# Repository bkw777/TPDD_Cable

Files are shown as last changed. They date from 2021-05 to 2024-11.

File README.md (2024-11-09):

# Cable for [Tandy Portable Disk Drive](http://tandy.wiki/TPDD)

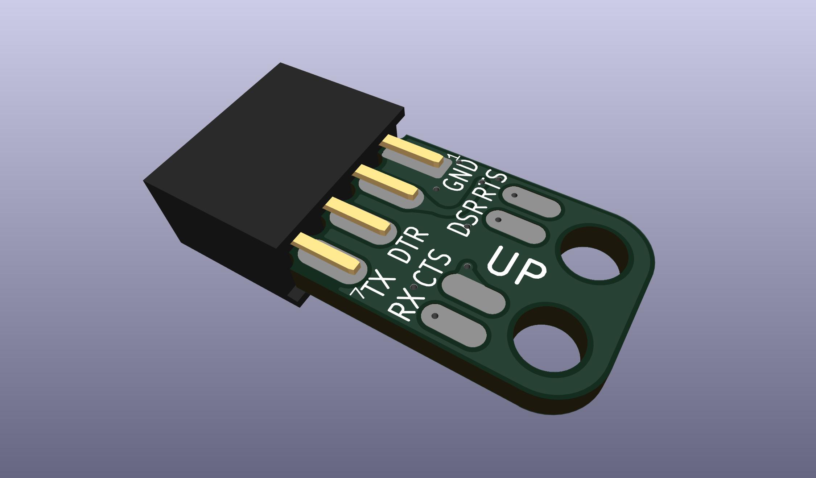
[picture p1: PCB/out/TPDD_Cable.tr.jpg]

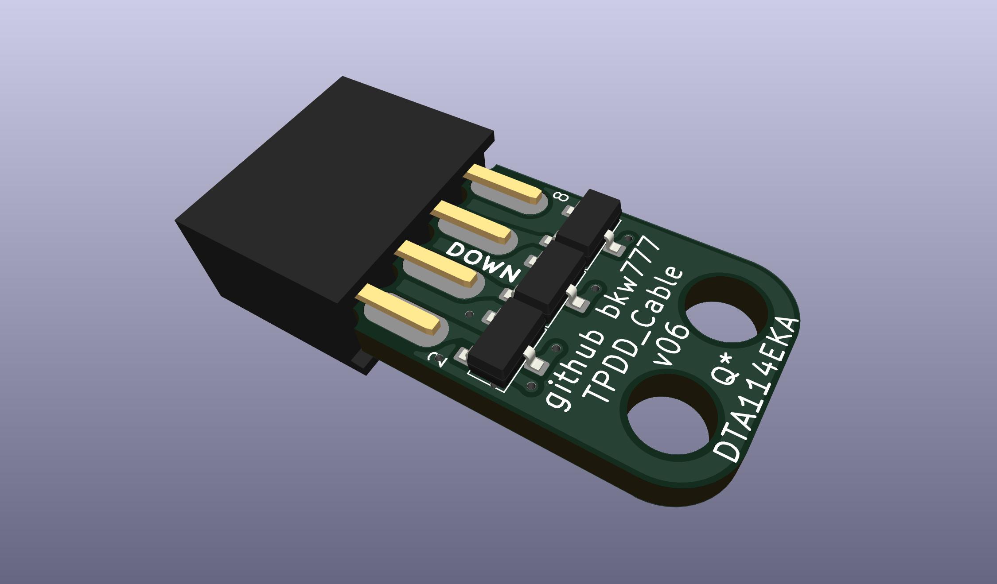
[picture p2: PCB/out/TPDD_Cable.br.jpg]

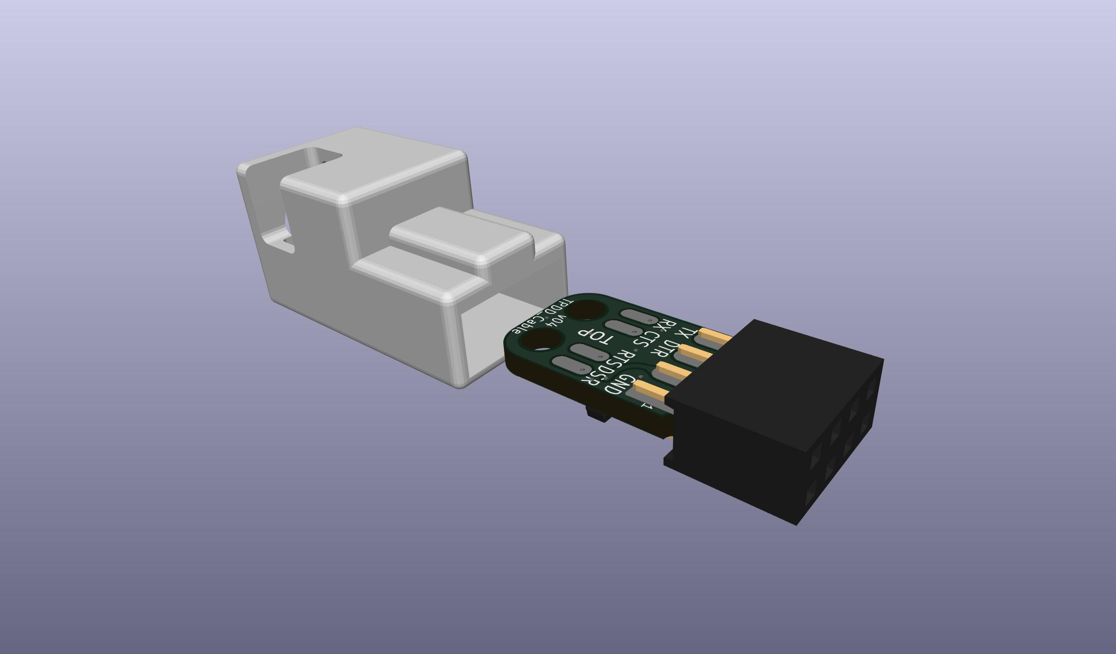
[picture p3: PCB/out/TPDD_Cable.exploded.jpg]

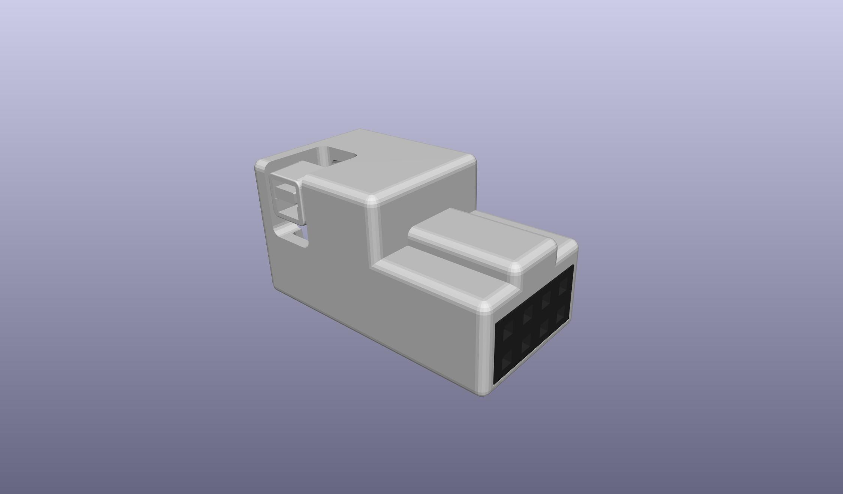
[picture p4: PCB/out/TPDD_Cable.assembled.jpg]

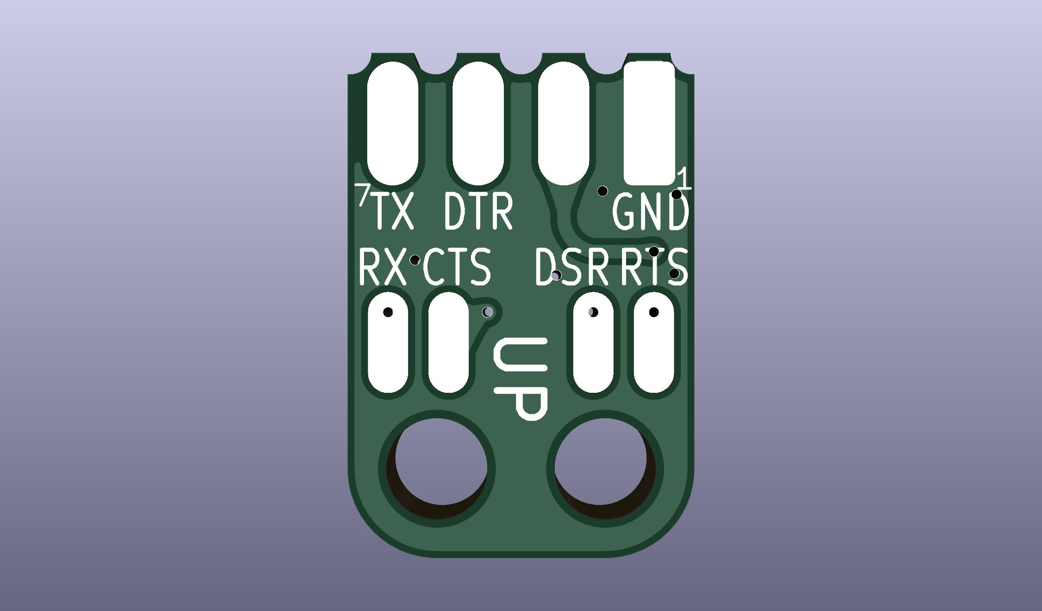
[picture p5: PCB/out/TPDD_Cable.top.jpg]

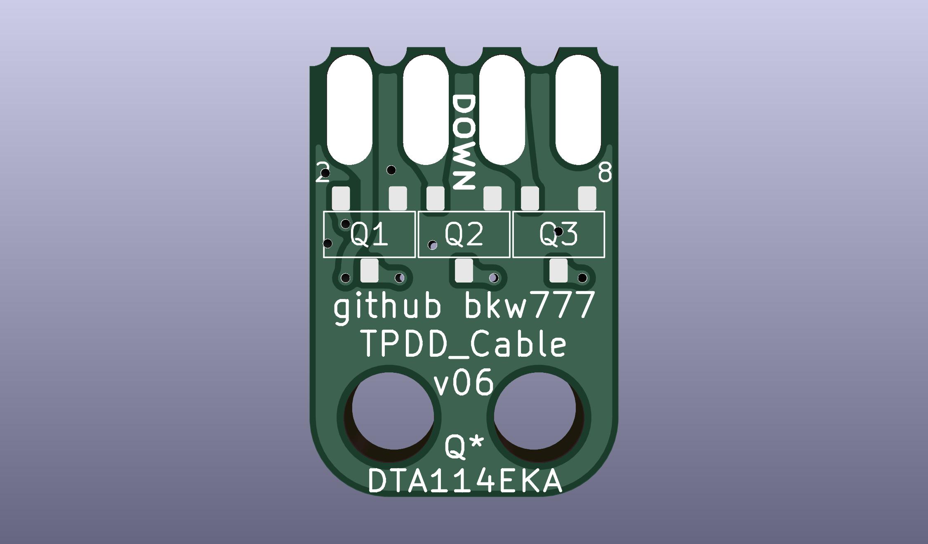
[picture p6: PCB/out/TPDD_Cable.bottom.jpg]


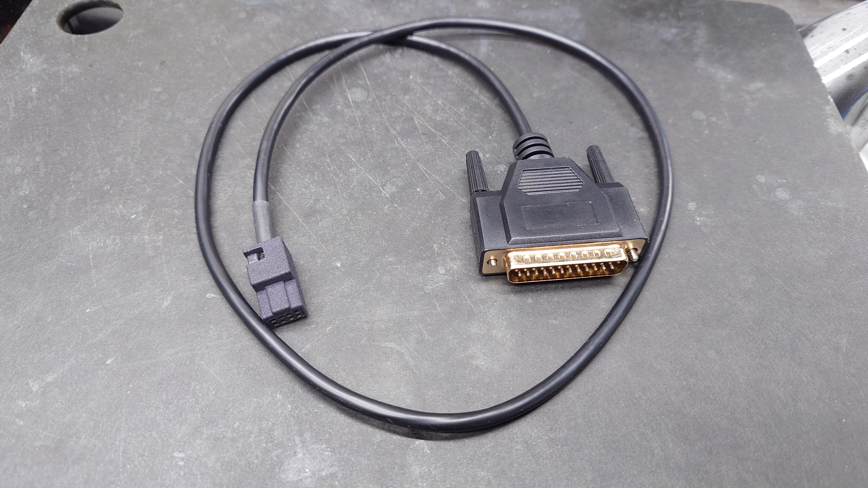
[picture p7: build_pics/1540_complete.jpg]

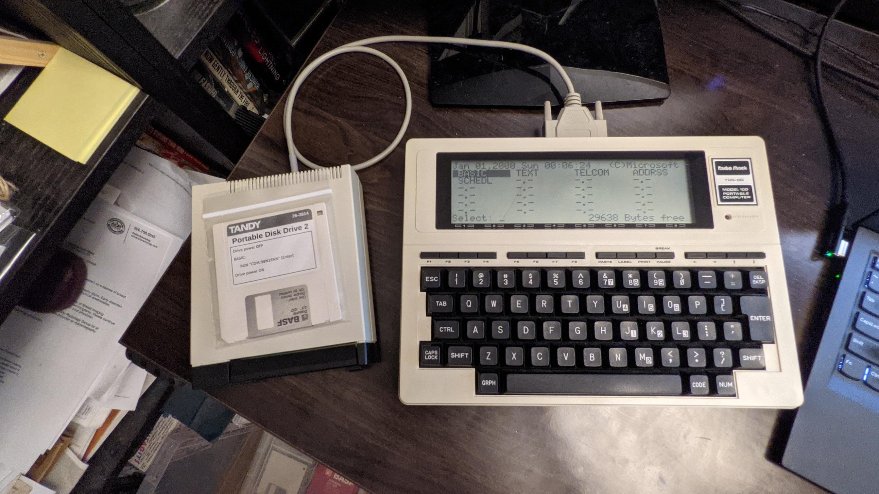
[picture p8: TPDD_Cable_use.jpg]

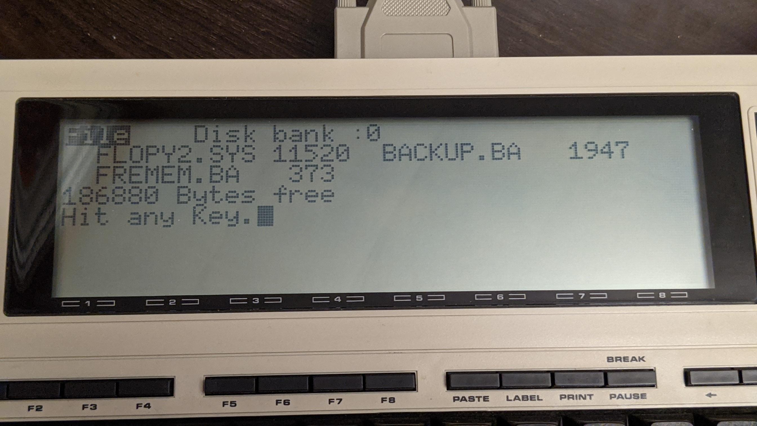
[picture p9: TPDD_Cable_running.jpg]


# Parts
PCB & Housing (and solder jig): [PCBWAY](https://www.pcbway.com/project/shareproject/TANDY_Portable_Disk_Drive_Cable.html)  
BOM: [DigiKey](https://www.digikey.com/short/87q1nv0f)  

The BOM includes a grey cable. This [black cable](https://www.digikey.com/short/wbpp81nt) can be substituted if you want.

# Directions

[pictures of build process](build_pics/build_pics.md)
<!--
Assembly pictures: <https://photos.app.goo.gl/TdYxGhzK94KT9rS78>
(old method before the 3d-printed housing)
-->

If you want to make 2 cables, one for Model 100 and one for PC/WP-2, then double the BOM components except for the cable, and cut the cable in half right in the middle.  
Otherwise just cut off the 9-pin plug to make one longer cable for Model 100 and other KC-85 clones.

## prepare the cable

Cut the unwanted plug off the cable.  
If building a Model 100 cable, cut off the 9-pin plug.  
If building a PC/WP-2 cable, cut off the 25-pin plug.  
If building both cables, cut the cable in half in the middle.

Strip off about 1 inch or 25mm of the cable jacket.  
Also cut the foil shield and the bare wire short right at the end of the jacket.

Apply a bit of flux to the ends of the loose wires.

Load up the soldering iron with a ball of solder and touch the soldering iron to the end of each wire long enough for the insulation to shrink itself back about 1-2mm and tin the end of the wire at the same time. You only need about 1mm of wire exposed and it's not worth trying to actually strip the insulation the normal way. Just heat the very tip end and it will melt and shrink itself back the perfect amount and the wire will end up tinned as well.

Insert the cable into the round opening on the housing and push the cable all the way through the housing and slide the housing about a foot back from the end of the cable.

Thread a 1 to 1-1/2 inch (25-30mm) piece of heatshrink onto the cable and slide back to the housing.  
Don't shrink it.

## Map the wire colors to the plug pin numbers

Print the wire color worksheet.

Put a DMM into continuity mode.

Use a jumper wire or meter lead with an alligator clip to grab one of the wires and connect to one lead of the DMM.

Probe with the other meter lead to touch each pin on the DB25 to find which pin that wire goes to.

Write the color of the wire for that pin number on the worksheet.

Repeat for all wires.

Cut the un-used wires short.
For the exact cable in the BOM and probably most cables, there will be 3 wires with no place on the PCB: a bare wire connected to both the DB25 shell and pin 1, a wire on pin 8, and a wire on pin 22.  
Cut all of those as short as possible right at the end of the cable jacket.

## prepare the pcb
Sand the edge of the pcb as neccessary to flatten any pointy bits left from the edge routing. The front edge is supposed to be castellated, so don't try to grind those away, but the front edge is supposed to be straight, so sand flat anything that sticks out from the rest.

Blunt or chamfer the rim of the drill holes on the bottom side of the pcb (the side with the chips). Use a countersink bit if you have one, or a drill bit. If nothing else a phillips screwdriver will barely work. You just want to blunt the sharp edge of the hole so the zip tie can be pulled through, don't grind a deep chamfer.

## solder the pcb
Solder the transistors onto the pcb.

Insert the pcb and the 2x4 connector into the solder jig.  
Face up or down doesn't matter.

Solder the 4 exposed pins on the 2x4 connector.

Remove the pcb from the jig and solder the other 4 pins on the 2x4 connector.

## solder the wires to the pcb
The signal names on the PCB are relative to the computer, aka the DTE side.  
Ex: The pad labelled RTS on the PCB connects to the computers RTS.

Follow your worksheet to match wire colors to the pads on the PCB.

Add solder to the 4 oval wire pads first so that you only need to touch the wire to solder it.

Start with the cable pointing the "wrong" way on the pcb, with the ends of the wires pointing towards the zip tie holes, ie the opposite direction from how it must be in the end, and solder the 4 wires that go to the 4 oval pads.

Then fold the cable over and fish the remaining 3 wires in between the 4 soldered wires towards their respective pins on the 2x4 connector. Keep all 3 of these wires inside of the first 4, ie the 2 outside wires of the 1st 4 remain the outermost wires when done. It's annoying but results in the least pinching & crossing of wires later.

Wash all flux from the pcb and wires.

## assemble the housing
Clean the end of the cable with alcohol where the heat-shrink will go if not done already.

Slide the heat-shrink 2mm past the end of the end of the cable jacket, just enough to cover the unused cut wires and shielding, and shrink it. Don't leave any more heat shrink in front of the jacket than necessary to cover the cut wires. You need to push the cable into the plug body as far as possible later, and excess heat-shrink will prevent the cable from inserting as far as it could.

**Make sure the transistors face DOWN, and the polarity key points UP**.

Slide the housing up over the pcb, or in other words pull the pcb into the housing.

The heat-shrink will want to catch on the front edge of the housing on the way in, and also on an internal lip at the rear of the housing on the way out.  
Squeeze and angle the cable to get the heat-shrink started into front of the housing, and pull the cable on the back 45 degrees up towards the top of the housing before pulling the heat-shrink all the way through so the heat-shrink doesn't catch on a lip at the bottom rear inside the housing.  
Regardless, if the heat-shrink gets dug up on the way through, just heat it again and it will smooth back out.

Once the pcb is all the way in, push the cable forward into the housing as far as possible while holding the pcb in with a finger over the front.  
Make sure the end of the jacket goes past the zip tie area.

Use pliers to put a small extra bend at the very tip of the zip tie, just the last 1-2mm right at the tip, in the same direction it's already bent (the direction it will bend to wrap around the cable).

Insert the zip tie pointing down into the one exposed hole in the pcb you can see, and push in with needle nose pliers until the tip comes out the top. Then you should be able to pull the tie out some more, thread it through the head and pull it the rest of the way. Stop before going all the way tight and jam the cable in as far as possible before cinching down tight.

If you didn't chamfer or blunt the bottom side of the drill holes, then you may have to push the zip tie in with pliers the whole way instead of pulling.

The zip tie does double duty. It both clamps the cable to the pcb and is also what locks the pcb into the housing so the pcb can't pull back out the front.

Once you have tested the cable and are sure the connections are correct, it would be best to inject some glue (C-A/super glue, vynil e6000/goop/etc) into the housing to immobilize the wires and to prevent the cable from working back out of the zip tie. If you're careful you could probably use hot glue by applying some just before inserting the cable, but you'll need to be careful to definitely get some on the pcb all the way back between the holes so that it grabs the heat shrink well, yet not plug up the holes where you will need to push the zip tie through.

## DONE

# Cable Wiring Options

For convenience, the tables below show the wire colors for the specific cables linked here.  
If you buy one of these exact specific cables, then your cable should match one of the tables below, but still double-check the wire colors to pin numbers before soldering.

If you use any other cable that isn't specifically from one of the links here, then ignore the colors in the tables below and map out your cables wire colors yourself with a DMM continuity beeper and one of the printable worksheets below.

The grey cable in the BOM, and the alternative black cable, has both a DB25M on one end and a DE9F on the other end, so you can use the same BOM to make either a "Model T" cable, or a PC cable, or one of each if you double up the other components.

## DB25 Male cable for TRS-80 Model 100 and other KC-85 clones


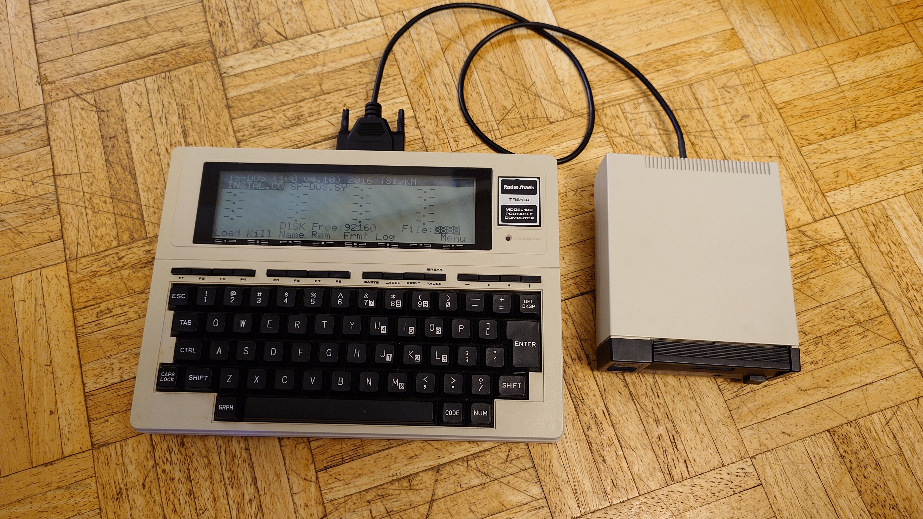
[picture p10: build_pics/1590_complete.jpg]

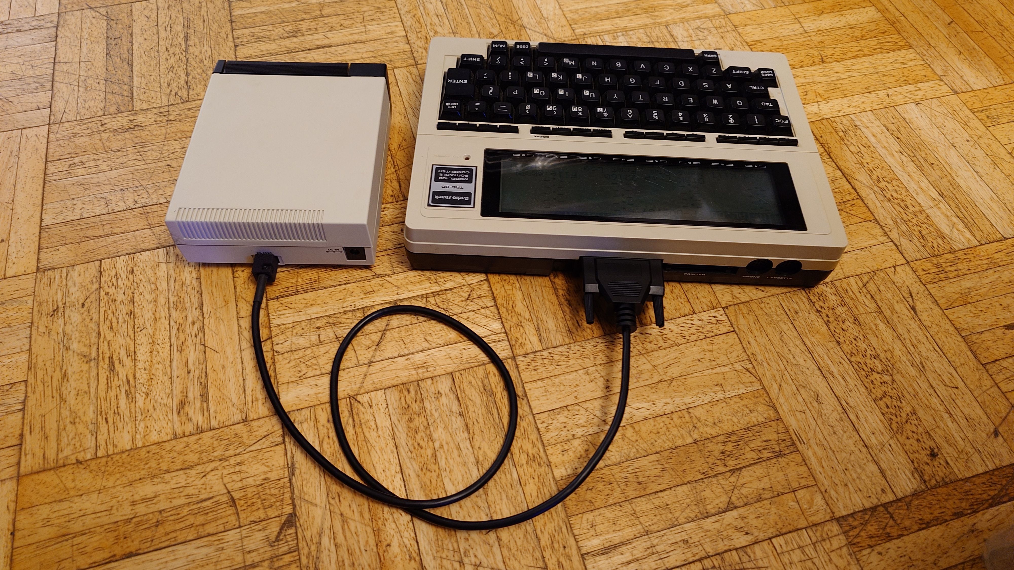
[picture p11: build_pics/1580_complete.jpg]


This is the standard version of the cable that replicates the cable that originally shipped with the TPDD and TPDD2.

The cable in the BOM supports this option.

It supports at least the following machines:

<ul>
Kyotronic KC-85<br>
TRS-80/TANDY Model 100, 102, 200, 600<br>
NEC PC-8201, PC-8300, PC-8401, PC-8500<br>
Olivetti M10

Any other machine with a *female* DB25 DTE RS-232 port. The female part is unusual but some other early machines besides these did have it this way also.
</ul>

[PRINTABLE WIRE COLOR WORKSHEET for KC-85 CLONES](DB25M_DTE_Wire_Chart.pdf)

<table border=1 cellspacing=0>
<caption>TPDD to Model 100</caption>
<tr>
<th colspan=2 width=35%>PCB PAD</th>
<th><a href="https://www.digikey.com/short/w8zz83q5">GREY CABLE</a></th>
<th><a href="https://www.digikey.com/short/wbpp81nt">BLACK CABLE</a></th>
<th colspan=2 width=35%>DB25 PIN</th>
</tr>
<tr>
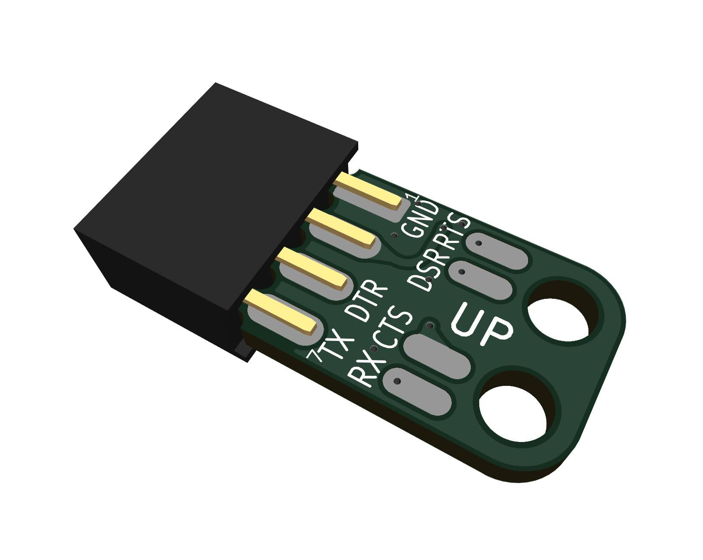
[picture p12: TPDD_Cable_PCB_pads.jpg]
<td rowspan=99 cellpadding=0></td>
<td>TX</td>
<td>Orange</td>
<td>Red</td>
<td>2</td>
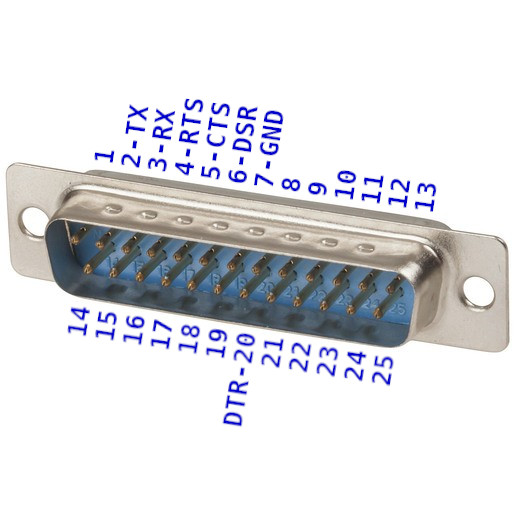
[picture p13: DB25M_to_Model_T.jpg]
<td rowspan=99 cellpadding=0></td>
</tr>
<!--<tr><td>TX</td><td>Orange</td><td>Red</td><td>2</td></tr>-->
<tr><td>RX</td><td>Red</td><td>Brown</td><td>3</td></tr>
<tr><td>RTS</td><td>Purple</td><td>Blue</td><td>4</td></tr>
<tr><td>CTS</td><td>Grey</td><td>Purple</td><td>5</td></tr>
<tr><td>DSR</td><td>Blue</td><td>Green</td><td>6</td></tr>
<tr><td>GND</td><td>Green</td><td>Yellow</td><td>7</td></tr>
<tr><td>DTR</td><td>Yellow</td><td>Orange</td><td>20</td></tr>
</table>

To verify the final result, check the following with a DMM in Continuity and Diode modes.

<table border=1 cellspacing=0>
<tr>
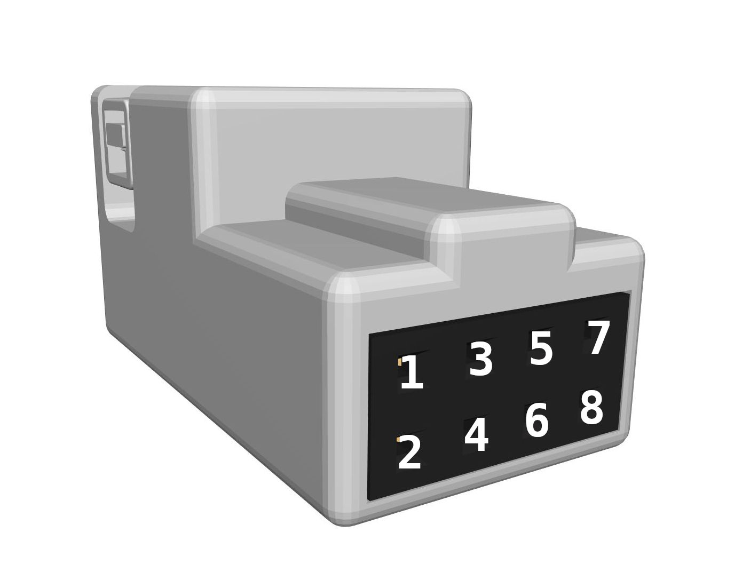
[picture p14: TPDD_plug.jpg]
<th rowspan=99 width=35%></th>
<th>BLACK</th><th>CONT</th><th>DIODE</th><th>RED</th>
<th rowspan=99 width=35%></th>
</tr>
<tr><td>1</td><td>BEEP</td><td></td><td>7</td></tr>
<tr><td>2</td><td>BEEP</td><td></td><td>4</td></tr>
<tr><td>3</td><td></td><td>1.7v</td><td>6</td></tr>
<tr><td>4</td><td></td><td>1.7v</td><td>5</td></tr>
<tr><td>5</td><td>BEEP</td><td></td><td>20</td></tr>
<tr><td>6</td><td></td><td>1.7v</td><td>3</td></tr>
<tr><td>7</td><td>BEEP</td><td></td><td>2</td></tr>
</table>

## DE9 Female cable for Standard PC 9-pin COM port

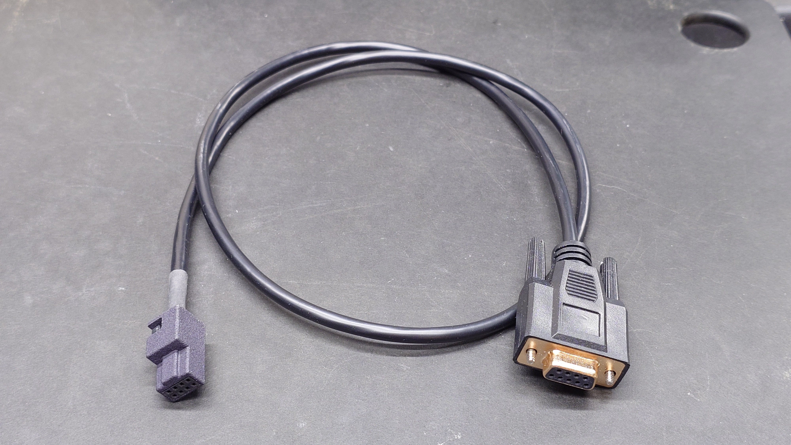
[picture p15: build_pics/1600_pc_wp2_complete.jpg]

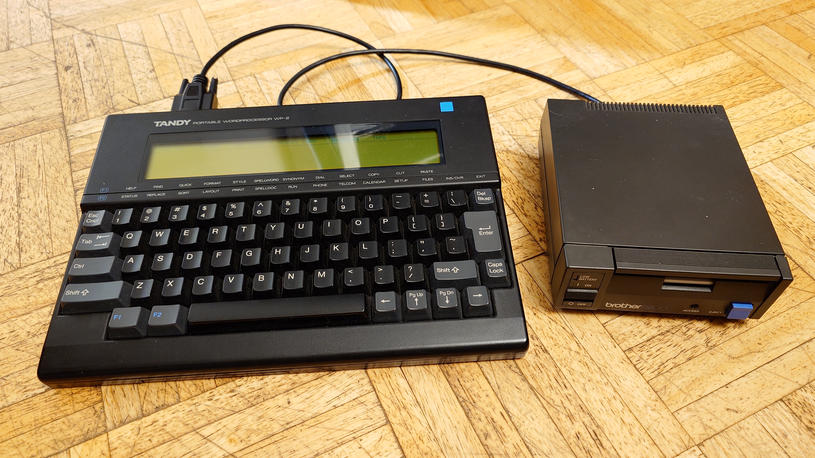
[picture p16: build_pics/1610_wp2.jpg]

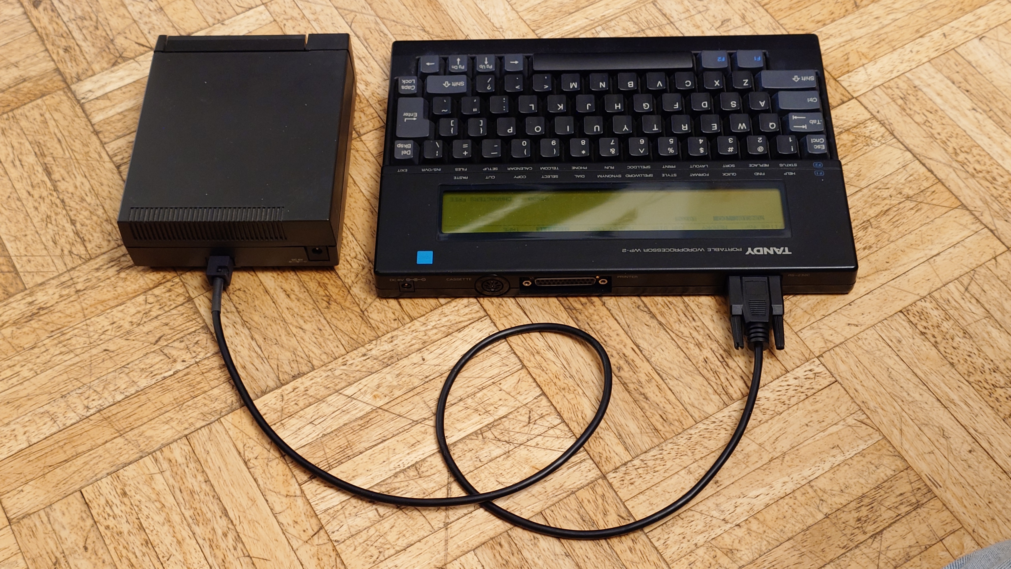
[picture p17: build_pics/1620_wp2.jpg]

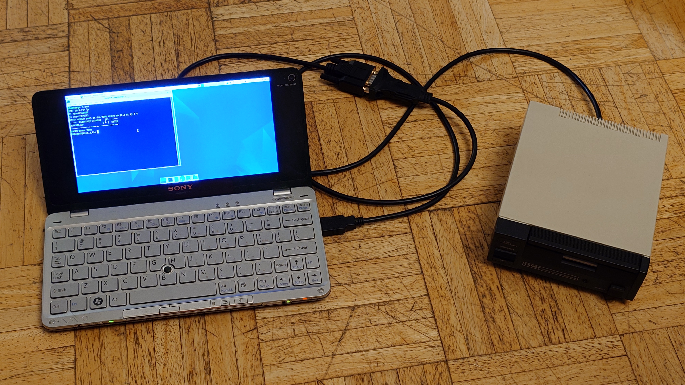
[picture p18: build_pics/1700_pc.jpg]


This version supports:
<ul>
Most PCs with 9-pin com ports<br>
usb-serial adapters<br>
TANDY WP-2<br>
Atari Portfolio<br>
Anything else with a standard male DE9 DTE RS-232 port
</ul>

IE this is for connecting the TPDD directly to a PC, which is not something you usually need to do.

This cable is useful for using [pdd.sh](https://githup.com/bkw777/pdd.sh) to take a raw disk image of a commercial disk or to re-create a disk from a disk image. You don't need this merely to copy normal files, but disks like the utility disks and the sardine dictionary disk are special and can't be copied any other way.

This is also useful if you have a Tandy WP-2 and want to use it's built-in TPDD support.

The cable in the BOM supports this option.

[PRINTABLE WIRE COLOR WORKSHEET for PC/WP-2](DE9F_DTE_Wire_Chart.pdf)

<table border=1 cellspacing=0>
<caption>TPDD to PC</caption>
<tr>
<th colspan=2 width=35%>PCB PAD</th>
<th colspan=2 width=35%>DE9 PIN</th>
</tr>
<tr>
<td rowspan=99 cellpadding=0></td>
<td>RX</td>
<td>2</td>
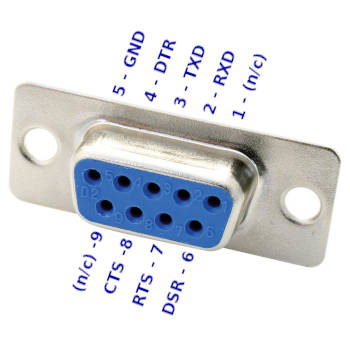
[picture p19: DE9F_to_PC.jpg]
<td rowspan=99 cellpadding=0></td>
</tr>
<!--<tr><td>RXD</td><td>2</td></tr>-->
<tr><td>TX</td><td>3</td></tr>
<tr><td>DTR</td><td>4</td></tr>
<tr><td>GND</td><td>5</td></tr>
<tr><td>DSR</td><td>6</td></tr>
<tr><td>RTS</td><td>7</td></tr>
<tr><td>CTS</td><td>8</td></tr>
</table>

To verify the final result, check the following with a DMM in Continuity and Diode modes.

<table border=1 cellspacing=0>
<tr>
<th rowspan=99 width=35%></th>
<th>BLACK</th><th>CONT</th><th>DIODE</th><th>RED</th>
<th rowspan=99 width=35%></th>
</tr>
<tr><td>1</td><td>BEEP</td><td></td><td>5</td></tr>
<tr><td>2</td><td>BEEP</td><td></td><td>7</td></tr>
<tr><td>3</td><td></td><td>1.7v</td><td>6</td></tr>
<tr><td>4</td><td></td><td>1.7v</td><td>8</td></tr>
<tr><td>5</td><td>BEEP</td><td></td><td>4</td></tr>
<tr><td>6</td><td></td><td>1.7v</td><td>2</td></tr>
<tr><td>7</td><td>BEEP</td><td></td><td>3</td></tr>
</table>

## Cambridge Z88
**UNTESTED**  
*The Cambridge Z88 RS-232 port has a non-standard pinout.*  
*Do not connect this cable to anything but a Cambridge Z88.*

The cable in the BOM does NOT support this option.  
Delete the cable from the pre-loaded DigiKey cart, and add [this one](https://www.digikey.com/short/mrf9n7nh) instead.

<table border=1 cellspacing=0>
<caption>TPDD to Z88</caption>
<tr>
<th colspan=2 width=35%>PCB PAD</th>
<th colspan=2 width=35%>DE9 PIN</th>
</tr>
<tr>
<td rowspan=99 cellpadding=0></td>
<td>TX</td>
<td>2</td>
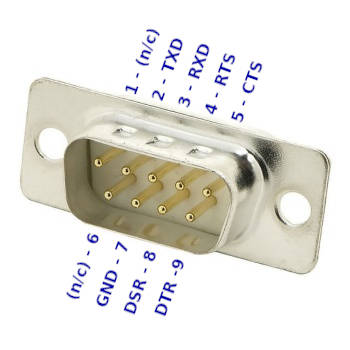
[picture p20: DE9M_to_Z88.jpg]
<td rowspan=99 cellpadding=0></td>
</tr>
<!--<tr><td>TX</td><td>2</td></tr>-->
<tr><td>RX</td><td>3</td></tr>
<tr><td>RTS</td><td>4</td></tr>
<tr><td>CTS</td><td>5</td></tr>
<tr><td>GND</td><td>7</td></tr>
<tr><td>DSR</td><td>8</td></tr>
<tr><td>DTR</td><td>9</td></tr>
</table>

# Credits / History
In the beginning, there was the [Marty Goodman Document](https://raw.githubusercontent.com/LivingM100SIG/Living_M100SIG/main/M100SIG/Lib-09-PERIFERALS/TPDD.DO), and it was good.

More recently, Rick Shear has taken a new and very careful look at a real cable, and the Marty Goodman doc, and has probably identified the "mystery" components that Marty Goodman talks about. It looks right, and the circuit does indeed work.  
[Rick's initial post](https://rsmicro.wordpress.com/2018/08/26/tpdd-cable/)  
[Rick's follow-up](https://rsmicro.wordpress.com/2018/09/08/built-tpdd-cable-comparison-to-oem/)

This cable uses the same transistors, but a different physical construction.

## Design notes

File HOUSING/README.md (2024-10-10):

The filenames indicate the body style and which pcb it supports.  
IE: stl/TPDD_Cable_Housing.3B.stl is housing type B for pcb type 3.

| | PCB Shape | Soldering Jig |
| --- | --- | --- |
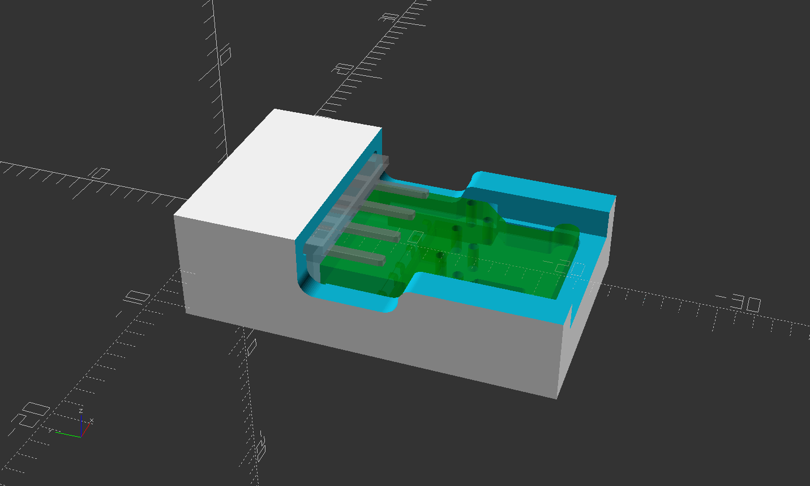
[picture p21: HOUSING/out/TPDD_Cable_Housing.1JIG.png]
| PCB 1 |  |  |
| PCB 2 |  |  |
| PCB 3 |  |  |

| | | | |
| --- | --- | --- | --- |
| Type A |  |  |  |
| Type B |  |  |  |
| Type C |  |  |  |
| Type D |  |  |  |

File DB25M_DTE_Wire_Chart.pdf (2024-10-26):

TPDD Cable to 25-pin RS-232 DTE Male DB25 cable for TRS-80 Model 100 and other Kyotronic KC-85 clones with Female DB25 RS-232 ports.

PCB PAD | WIRE COLOR | DB25 PIN#
| | | SH

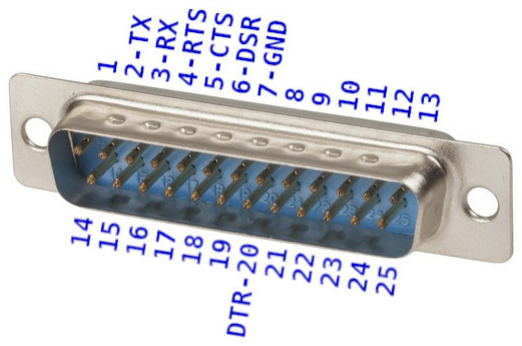
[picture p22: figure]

| | | 1

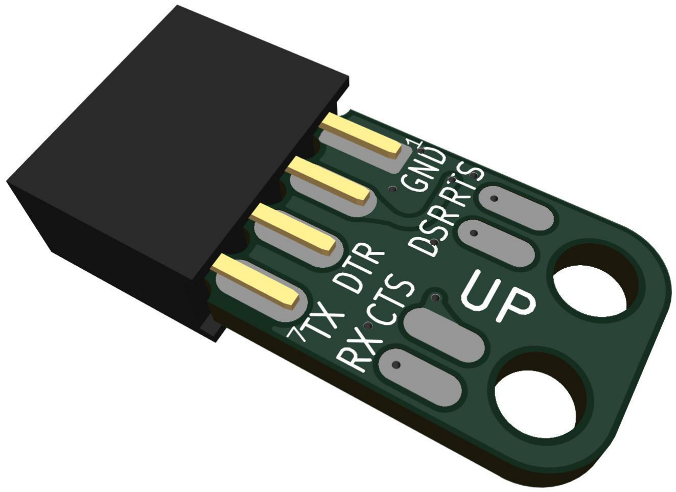
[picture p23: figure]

| TX | | 2
| RX | | 3
| RTS | | 4
| CTS | | 5
| DSR | | 6
| GND | | 7
| | | 8
| DTR | | 20
| | | 22

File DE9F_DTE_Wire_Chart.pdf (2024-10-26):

TPDD Cable to 9-pin RS-232 DTE Female DE9 cable for standard PC COM ports, usb-serial adapters, TANDY WP-2, and others with male DE9 RS-232 ports.

PCB PAD | WIRE COLOR | DE9 PIN#
| | | SH

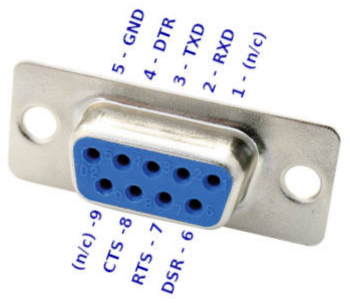
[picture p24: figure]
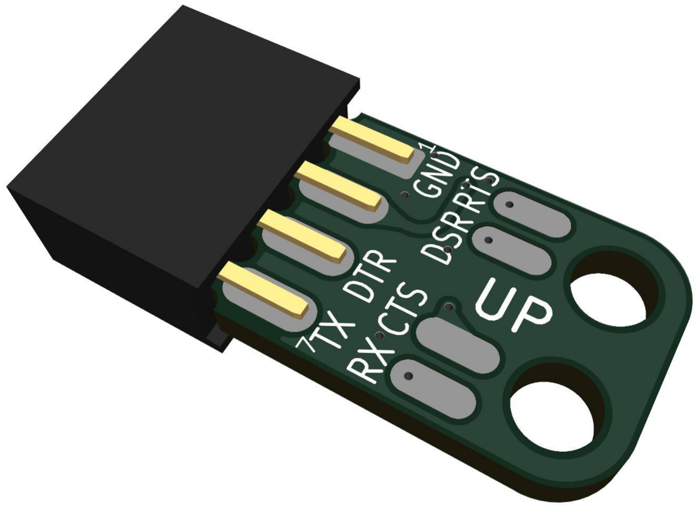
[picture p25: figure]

| | | 1
| RX | | 2
| TX | | 3
| DTR | | 4
| GND | | 5
| DSR | | 6
| RTS | | 7
| CTS | | 8
| | | 9

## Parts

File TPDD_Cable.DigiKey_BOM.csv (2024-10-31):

Index | Quantity | Part Number | Manufacturer Part Number | Description | Customer Reference | Available | Backorder | Unit Price | Extended Price USD
1 | 1 | 367-1184-ND | 30-9506-29 | CABLE ASSY DB09 TO DB25 1.83M |  | 1 | 0 | 6.31000 | 6.31
2 | 3 | DTA114EKAT146CT-ND | DTA114EKAT146 | TRANS PREBIAS PNP 50V SMT3 |  | 3 | 0 | 0.15000 | 0.45
3 | 1 | A22V1/4B-0.5-ND | F221V1/4 BK203 | HEAT SHRINK TUBE 1/4 BK 0.5' |  | 0 | 1 | 0.94000 | 0.94
4 | 1 | 952-1789-ND | M20-7830442 | CONN RCPT 8POS 0.1 GOLD PCB |  | 1 | 0 | 2.01000 | 2.01
5 | 10 | 3240781-ND | 3240781 | CBL TIE LOCKING BLACK 18LB 3.86" |  | 10 | 0 | 0.01400 | 0.14

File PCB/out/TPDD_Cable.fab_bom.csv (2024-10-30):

Reference | Value | Datasheet | Footprint | Qty | DNP | MPN
J1 | TPDD_RS-232C | datasheets/M20-783.pdf | 000_LOCAL:2x4x2.54mm_edge_mount | 1 |  | M20-7830442
Q1,Q2,Q3 | DTA114EKA | datasheets/dta114ee3-e.pdf | 000_LOCAL:SC-59 | 3 |  | DTA114EKA

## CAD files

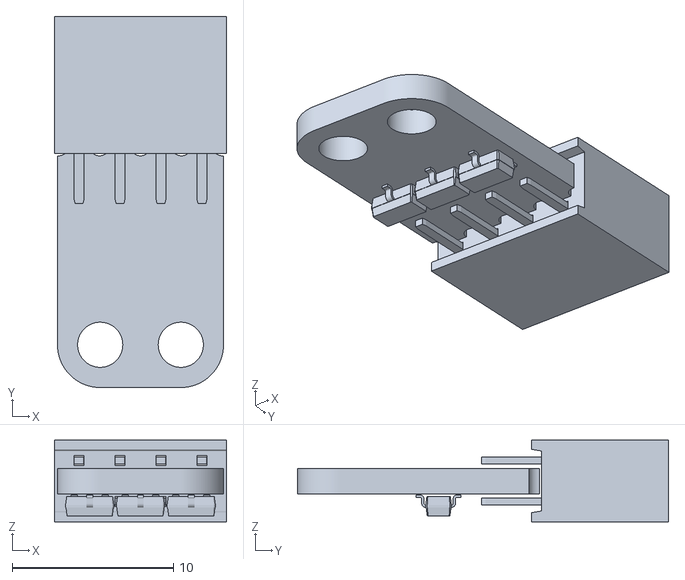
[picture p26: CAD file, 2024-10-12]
HOUSING/inc/TPDD_Cable.stl
10.7 x 23.0 x 5.08

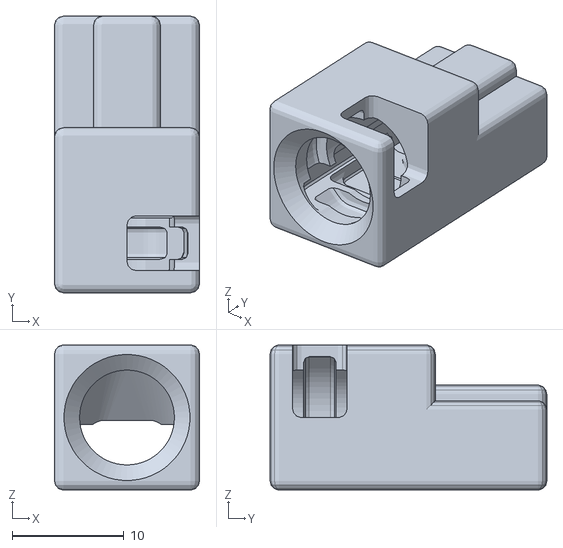
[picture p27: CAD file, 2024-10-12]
HOUSING/out/TPDD_Cable_Housing.stl
13.0 x 24.8 x 13.0

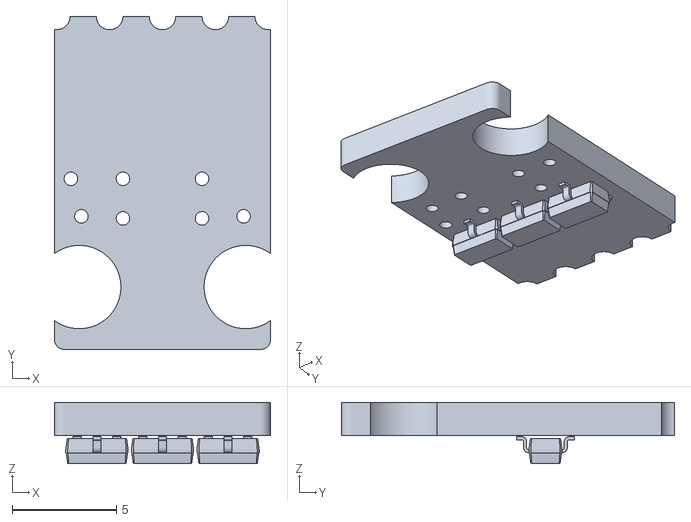
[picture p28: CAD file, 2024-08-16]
HOUSING/inc/TPDD_Cable_M4-tie.stl
10.4 x 16.0 x 2.95

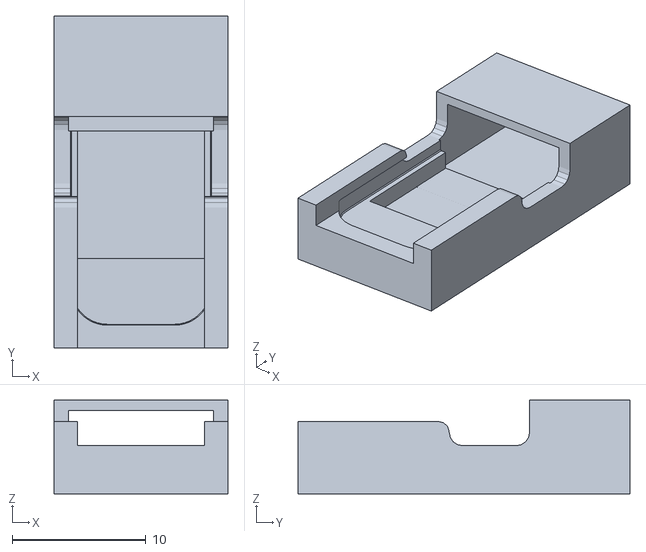
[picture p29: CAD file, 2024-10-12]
HOUSING/out/TPDD_Cable_solder_jig.stl
13.0 x 24.8 x 7.00

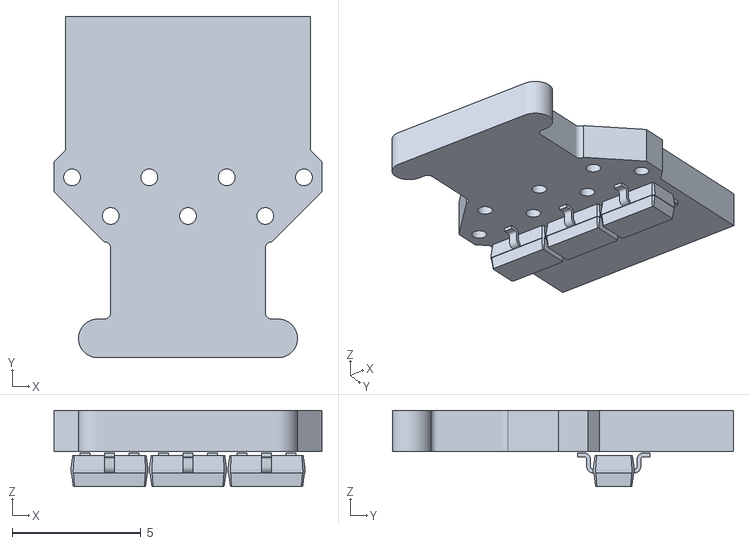
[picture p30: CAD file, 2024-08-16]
HOUSING/inc/TPDD_Cable_1.stl
10.4 x 13.2 x 2.95

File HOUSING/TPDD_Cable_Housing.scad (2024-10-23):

/*
 * Plug housing for TPDD_Cable
 * v007
 */

// See DEBUGGING at the bottom to enable preview cut-aways.
// They are down there instead of up here so that you can
// use calculated variables to set the cut plane position.

// ==== CUSTOMIZABLE OPTIONS ====

// housing or solder jig
part = "housing";
//part = "jig";

// 1 = original dog bone shape, M3 ziptie, tht wire pads
// 2 = holes for M3 ziptie, smt wire pads
// 3 = clipped holes for M4 ziptie, smt wire pads
pcb_version = 2;

// Cable diameter including heat-shrink.
// Most cables are 5mm plus heat-shrink adds another mm.
// Cables2Go #03019 & #02518 are only 3.8mm diameter.
// Body style A is too small for anything except those cables, with no heat-shrink added.
cable_diameter = 6;

housing_style = 
        cable_diameter <= 4 ? "A" :
        cable_diameter <= 5 ? "B" :
        "C" ;

/*
 A - smallest and neatest
     Not actually usable except with thin (4mm) cable
     and no heat shrink.

 B - attempt to compromize between A and C
     small as possible but a bit more vertical room for cable

 C - most practical
     full cable fit with no forcing
     even possibly a 2nd layer of heatshrink

 D - chonky boy, easy to grab
     handle shorter than C and cable not centered vertically

 Theoretical max cable sizes without deforming.
 For style A, a 5mm cable with one layer of heatshrink can
 be deformed enough to fit with crimper pliers.
 Cables2Go #03019 & #02518 are only 3.8mm diameter.
 
 A - ECHO: "cable vertical gap", 4.02
 B - ECHO: "cable vertical gap", 5.42
 C - ECHO: "cable vertical gap", 6.82
 D - ECHO: "cable vertical gap", 6.22

*/

// "min", "tie", or arbitrary
// min = Automatic minimum possible handle length.
//       Handle ends at minimum_rear_wall past the cable tie slot.
// tie = Automatic make the handle however long it takes so that
//       the cable tie lands in the center.
handle_length = (
        housing_style=="B" ? "min" :
        housing_style=="C" ? "min" :
        housing_style=="D" ? 20 :
        "min");

// If this value is >3, then 1mm is also
// automatically added to the front plug length
// to move the handle 1mm further away from the drive,
// to clear the edge of the recess around the port.
handle_extra_width = (
        housing_style=="D" ? 2 :
        0);

// "square" or arbitrary
// "square" = copy handle width to make the body square
// If the value (arbitrary or generated) is >1, then 1mm
// is also automatically added to the front plug length
// to move the handle 1mm further away from the drive,
// to clear the edge of the recess around the port.
handle_extra_height = (
        housing_style=="B" ? 1 :
        housing_style=="C" ? "square" :
        housing_style=="D" ? handle_extra_width :
        0);

// make the cable pocket this much bigger than
// cable + heat shrink
cable_extra_radius = (
        housing_style=="A" ? 1 :
        housing_style=="C" ? 0.75 :
        0.5);

// "center", "pcb", or arbitrary
// center = Position the cable in the center of the handle height.
// pcb = Position the cable as though the bare cable
//       (no heat_shrink_thickness or cable_extra_radius)
//       is resting on top of the pcb.
cable_z_position = (
        housing_style=="B" ? 2.5 :
        housing_style=="C" ? "center" :
        housing_style=="D" ? "pcb" :
        "center");

cable_chamfer_depth = (
        housing_style=="B" ? 1 :
        housing_style=="C" ? 1.5 :
        housing_style=="D" ? 1 :
        1);

// the vertical cylindrical cuts on the sides
// grip_cut_depth tries for this,
// but automatically adjusts itself
// to avoid violating min-wall-thickness
grip_cut_depth = (
        housing_style=="C" ? 0 :
        1);

// The conical cuts on the top & bottom corners.
// This really depends on what grip_cut_depth actually
// resolves to after adjusting itself to min_wall_thickness.
// Maybe it should be an adjustment value added to grip_cut_depth?
grip_chamfer_depth = (
        housing_style=="B" ? 0.8 :
        housing_style=="C" && pcb_version == 1 ? 0.8 :
        housing_style=="C" && pcb_version == 2 ? 0 :
        housing_style=="C" && pcb_version == 3 ? 1.2 :
        housing_style=="D" ? 1.3 :
        0.8);

// adds space between all parts in all directions
// "SLS", "FDM", or arbitrary
// SLS = 0.1
// FDM = 0.2
fitment_clearance = "SLS";

corner_radius = 0.8;

// Commercial SLS/MJF often 0.8mm
minimum_wall_thickness = 0.8;

// Minimum material from cable tie to rear end
// this sets the minimum overall handle length
// based on the location of the zip-tie + N
// if handle_length == "min"
minimum_rear_wall = 2;

// zip tie size M3 or M4
cable_tie_size = (
        pcb_version == 3 ? 4:
        3);

// 0 to remove heat-shrink
heat_shrink_thickness = 0.5; //0;

// curve smoothness
$fa = 6;
$fs = 0.4;
//$fn = 36;

// ===============================================================

JIG = (part=="jig")?true:false;

t = 2.54; // tenth inch
o = 0.1;  // overlap / overcut
e = 0.001; // epsilon
mw = minimum_wall_thickness;
cr = JIG?0:corner_radius;

fc = (
  fitment_clearance == "SLS" ? 0.1 :
  fitment_clearance == "FDM" ? 0.2 :
  is_num(fitment_clearance) ? fitment_clearance :
  0.1);

// PCB dimensions
pm = pcb_version;
ph = 1.6;      // pcb thickness

pw = (         // pcb width
//  pm==1 ? 10.4:
  pm==2 ? 10.3:
  pm==3 ? 10.4:
  10.4);

pw2 = (        // pcb width 2
  pm==1 ? 8.5:
  0);

pl = (         // pcb length
//  pm==1 ? 13.25:
  pm==2 ? 15:
  pm==3 ? 16:
  7.8);

pl2 = (        // pcb length 2
  pm==1 ? 13.25:
  0);

pty = (        // pcb transistors center Y from pcb edge
  pm==2 ? 6.25:
  pm==3 ? 6.2:
  4.655);

pwy = (        // wires furthest Y from pcb edge
  pm==2 ? 10.1:
  pm==3 ? 10.1:
  8.075);

pcr = (        // pcb corner radius
//  pm==1 ? 0.75:
  pm==2 ? 2.65:
  pm==3 ? 0.5:
  0.75);

ptw = 9.3;     // pcb transistors width

components_height = 1.4; // TO-236-3, SC-59, SOT-23-3

h2h = (        // zip tie hole to hole
//  pm==1 ? 0:
  pm==2 ? 5:
//  pm==3 ? 0:
  0);

zty = (        // zip tie position Y from pcb front edge
//  pm==1 ? 10.25:
  pm==2 ? 12.35:
  pm==3 ? 13:
  10.25);

pfc = (     // extra fitment clearance for pcb
  JIG ? fc: // jig needs the printer tolerance but no extra
  fc+0.12); // normal needs the printer tolerance plus extra

pcw = pfc+pw+pfc;  // pcb slot full width

// TPDD port dimensions
owl = 13;      // outer width lower, horzontal part width

// Plug height, lower/horizontal part.
// Measured original plug: 7.5 - centered on pins
// Measured hole: 8.5 - not centered on pins, extra 1mm all on top
// Allow for variability in male 2x4 pin header solder position
ohl = (          // outer height lower
  JIG ? 7:
  8);

// Plug width, upper/vertical part (the polarity key)
// Measured original cable: 5.4
// Measured hole: 6.5
owu = 6;       // outer width upper

// Plug height, upper/vertical part.
// Measured original cable: 8.6
// Measured hole: 10.0-10.2
ohu = 9.4;       // outer height upper

// Distance from center of 2x4 pins to exterior bottom.
// The port opening is not centered vertically on the 2x4 pins.
// It's the same on all drives not just a manufacturing variance
// on one particular drive. All real original cables in all
// drives have the cable lightly or firmly touching the bottom
// and 1mm free space on top.
// This establishes where the floor is relative to the pins,
// and the rest of the housing grows up from there.
//ohb = ih/2+1.1;
// Original cables more like 3.7, but they actually rub.
ohb = 3.6;    // outer height bottom  z=0 to exterior bottom

// Plug length/depth, ie the keyed part,
// at the recessed surface immediately around the port.
// The recessed surface extends 3mm left & right,
// 1mm up, and 0mm down from the port. If the handle body is
// wider or taller than that, then this gets 1mm added to it
// automatically later.
// 11.5 is from the insulator at the base of the pins
// to the outside surface of the case, but the connector
// can't actually go that deep
//plug_len = 11.5; // length/depth of keyed part
plug_len = 9; // length/depth of keyed part

// cable
cir = cable_diameter/2;            // cable inside radius
cor = cir + heat_shrink_thickness; // cable outside radius
cpr = cor + cable_extra_radius;    // cable pocket radius
ccd = cable_chamfer_depth;         // cable chamfer depth

// 2x4 connector body
iw = t*4+0.5;//10.6; // 2.54 * 4 + 0.4
ih = t*2;//5.1;  // 2.54 * 2
id = 8.5;

// Height of the flux wash standoffs on the 2x4 connector.
// The 2x4 connector depth dimension includes the standoffs,
// but the pcb soldered on edge does not stop at the standoffs,
// so this tells where the pcb actually is relative to the
// full connector depth dimension.
pcb_inset = 0.5;
// pcb v1 has no castellations
// so it will push connector type b out
connector_outset = (
  (pm==1&&connector_model=="b")?pcb_inset:
  0);

hew = handle_extra_width;  // handle extra width
hw = hew+owl+hew ;         // handle width
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

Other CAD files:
PCB/out/TPDD_Cable.step
HOUSING/inc/handy.scad

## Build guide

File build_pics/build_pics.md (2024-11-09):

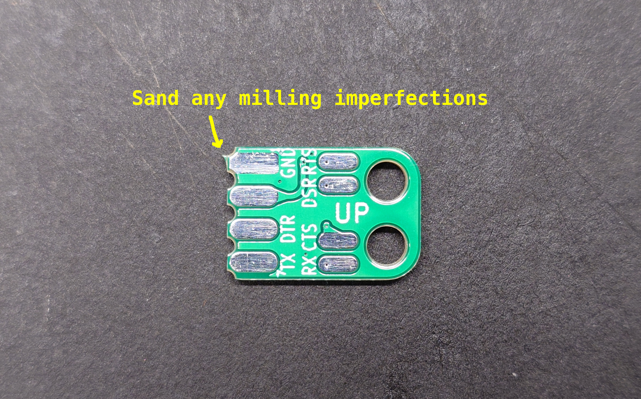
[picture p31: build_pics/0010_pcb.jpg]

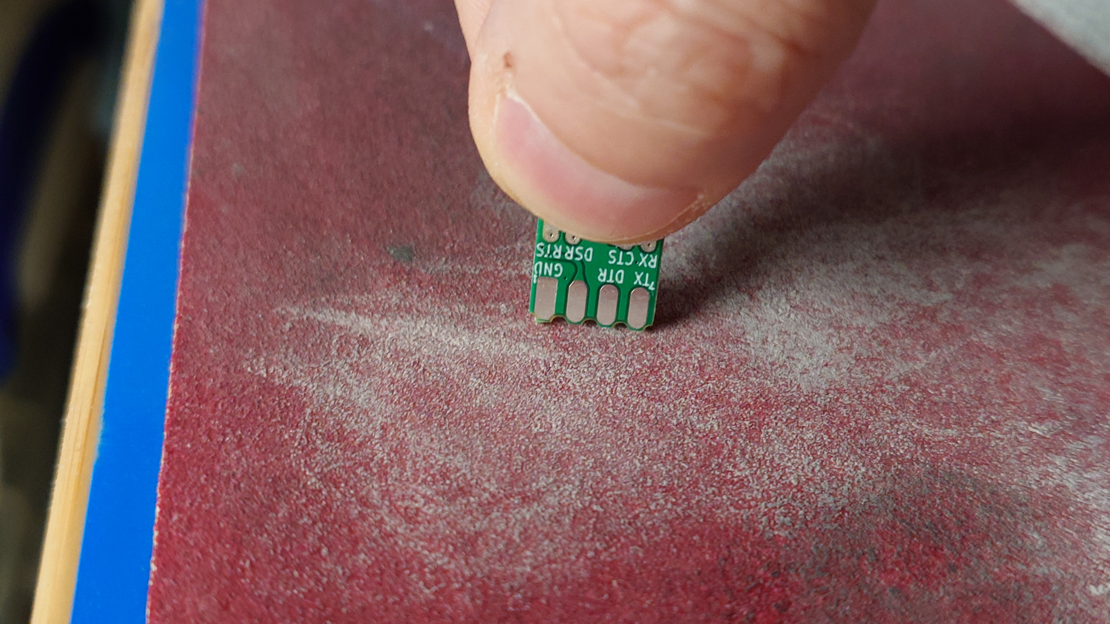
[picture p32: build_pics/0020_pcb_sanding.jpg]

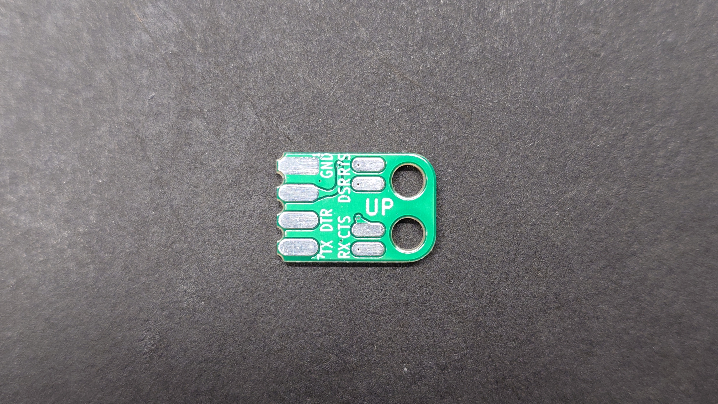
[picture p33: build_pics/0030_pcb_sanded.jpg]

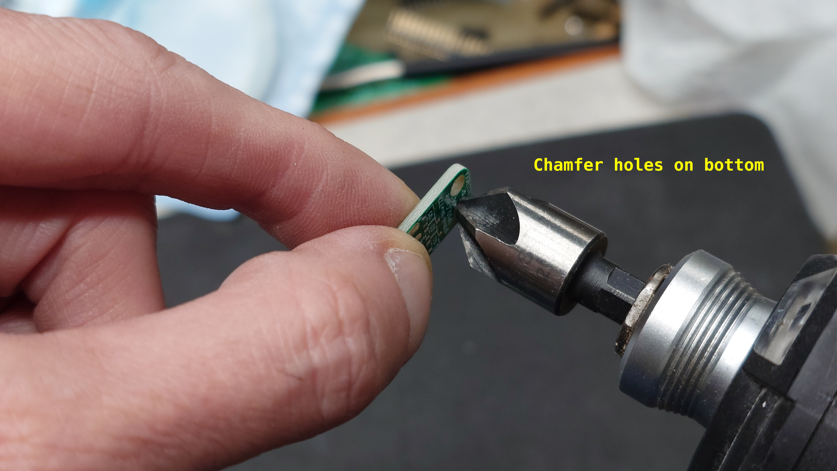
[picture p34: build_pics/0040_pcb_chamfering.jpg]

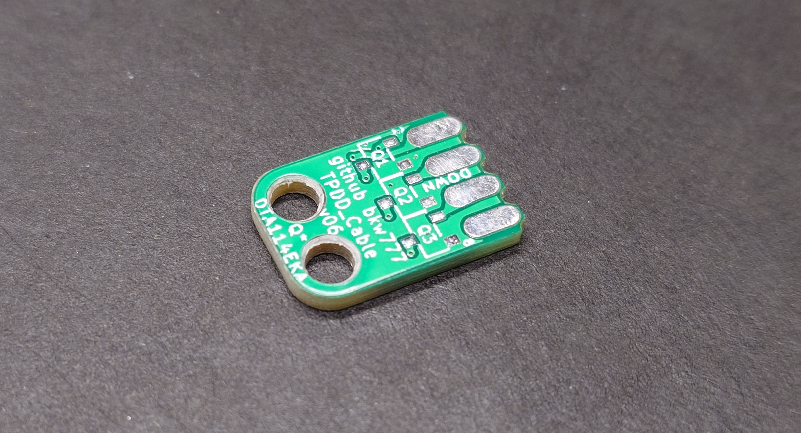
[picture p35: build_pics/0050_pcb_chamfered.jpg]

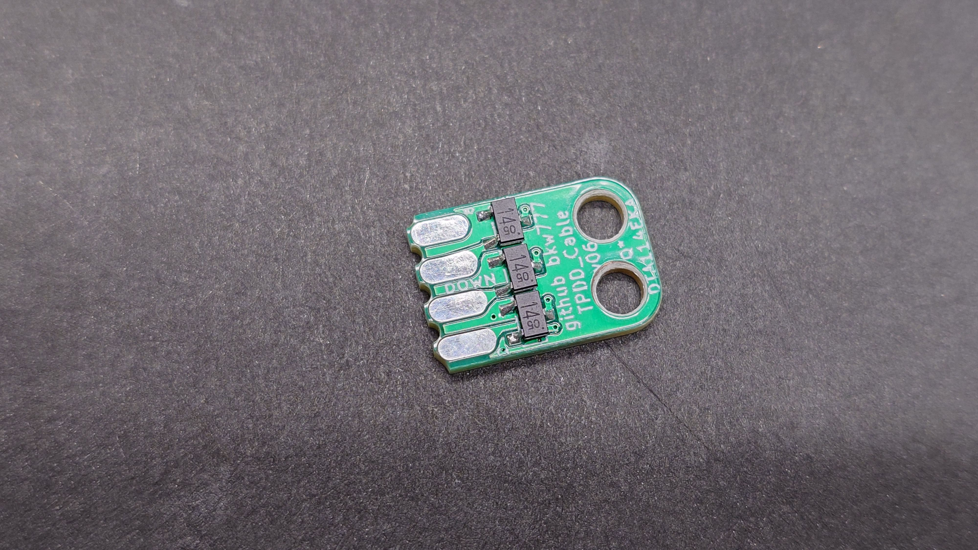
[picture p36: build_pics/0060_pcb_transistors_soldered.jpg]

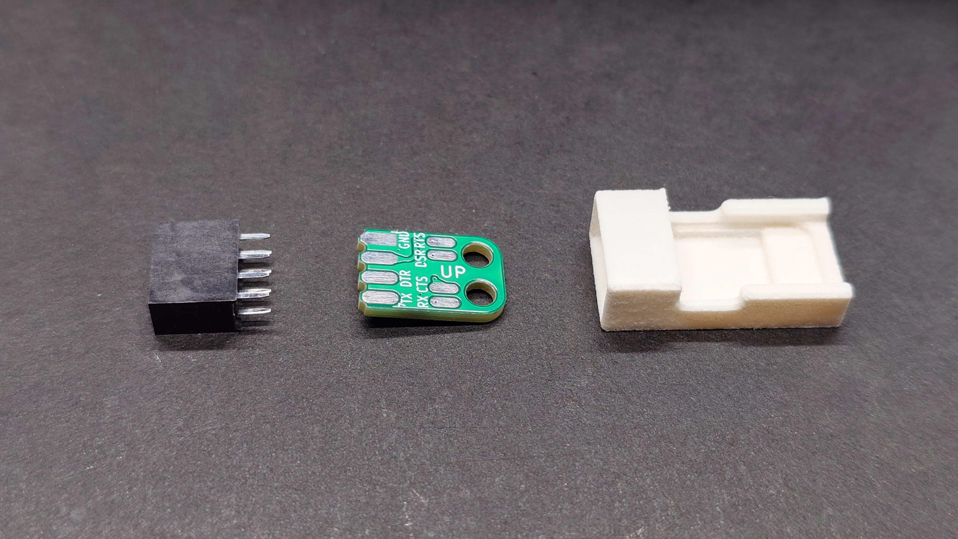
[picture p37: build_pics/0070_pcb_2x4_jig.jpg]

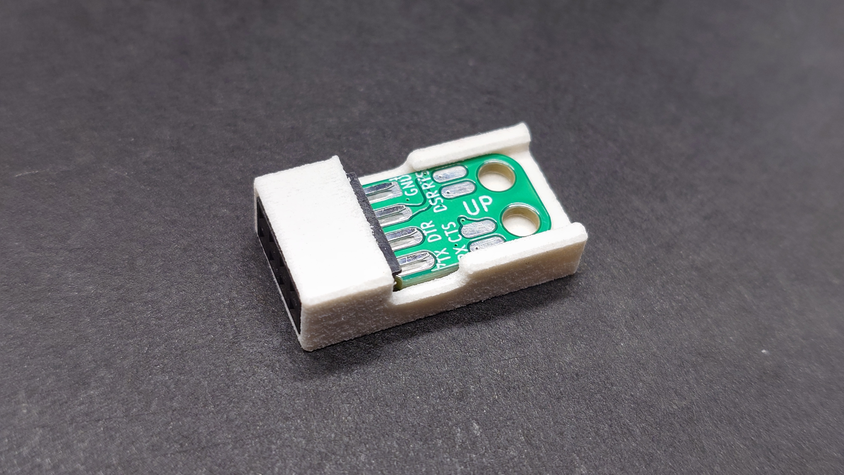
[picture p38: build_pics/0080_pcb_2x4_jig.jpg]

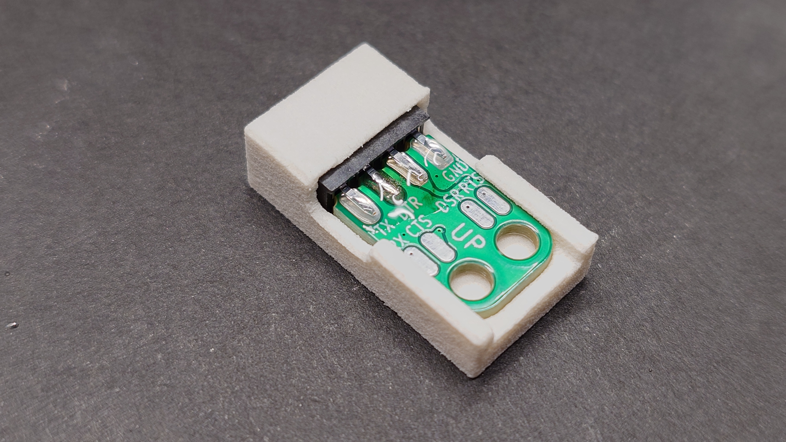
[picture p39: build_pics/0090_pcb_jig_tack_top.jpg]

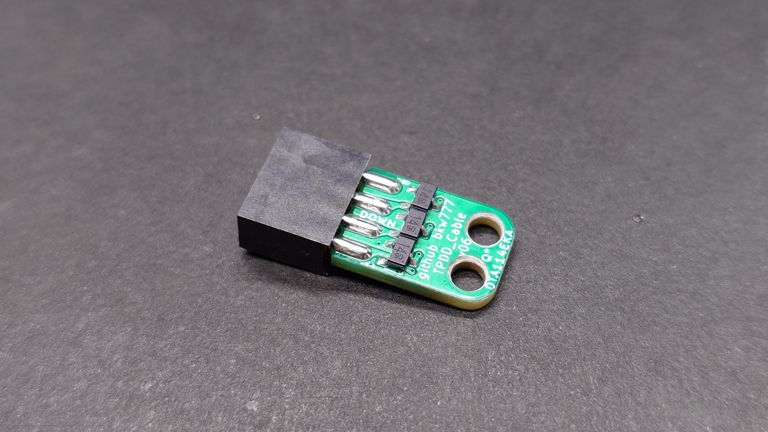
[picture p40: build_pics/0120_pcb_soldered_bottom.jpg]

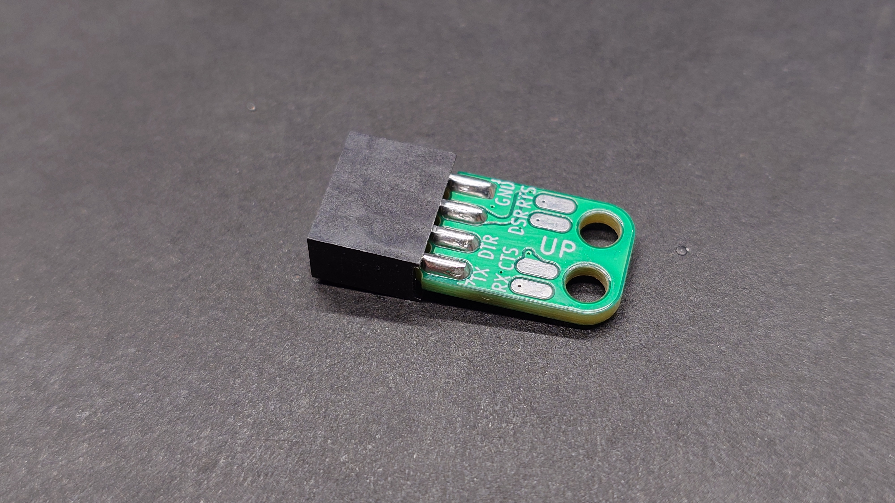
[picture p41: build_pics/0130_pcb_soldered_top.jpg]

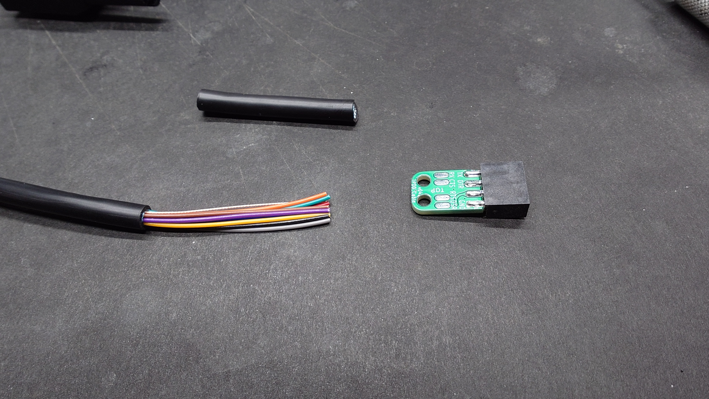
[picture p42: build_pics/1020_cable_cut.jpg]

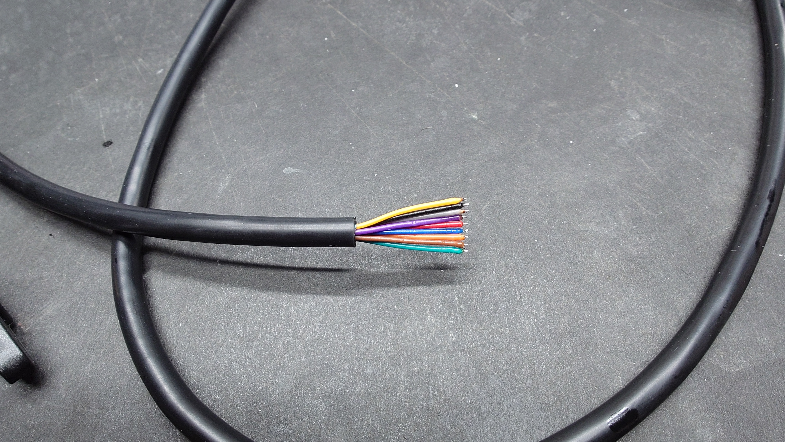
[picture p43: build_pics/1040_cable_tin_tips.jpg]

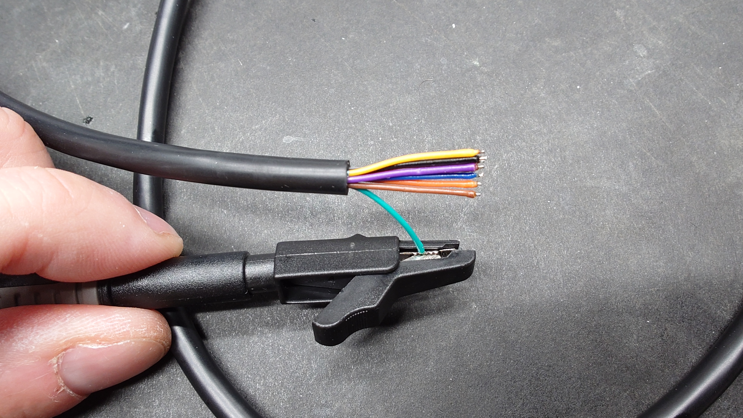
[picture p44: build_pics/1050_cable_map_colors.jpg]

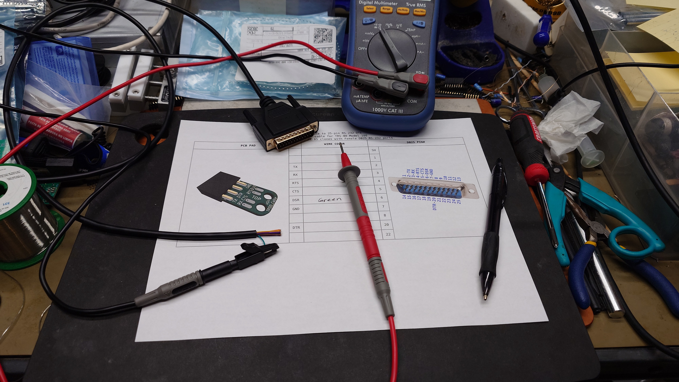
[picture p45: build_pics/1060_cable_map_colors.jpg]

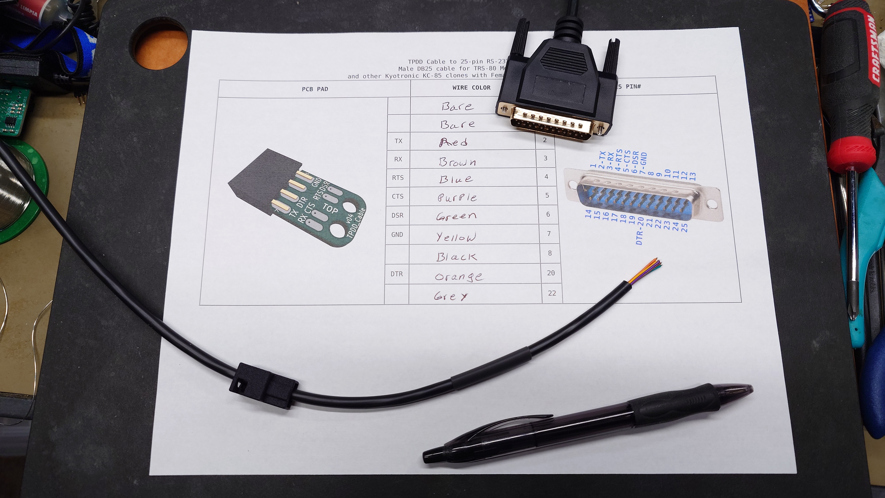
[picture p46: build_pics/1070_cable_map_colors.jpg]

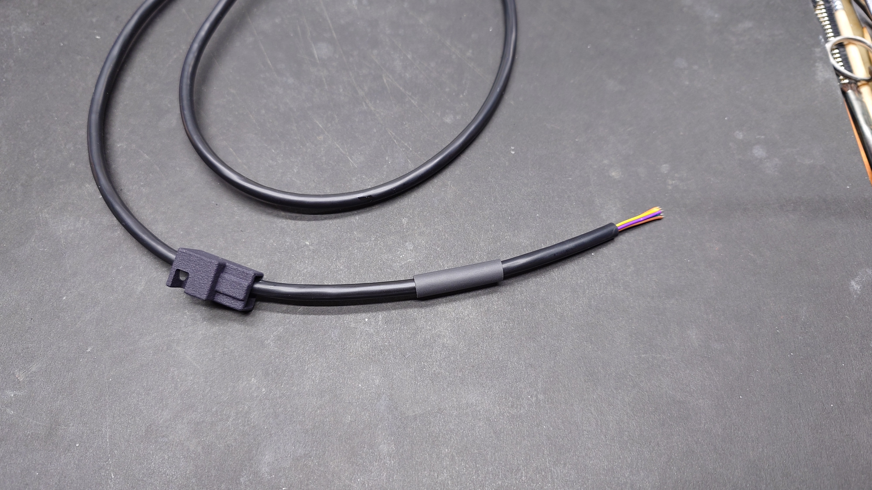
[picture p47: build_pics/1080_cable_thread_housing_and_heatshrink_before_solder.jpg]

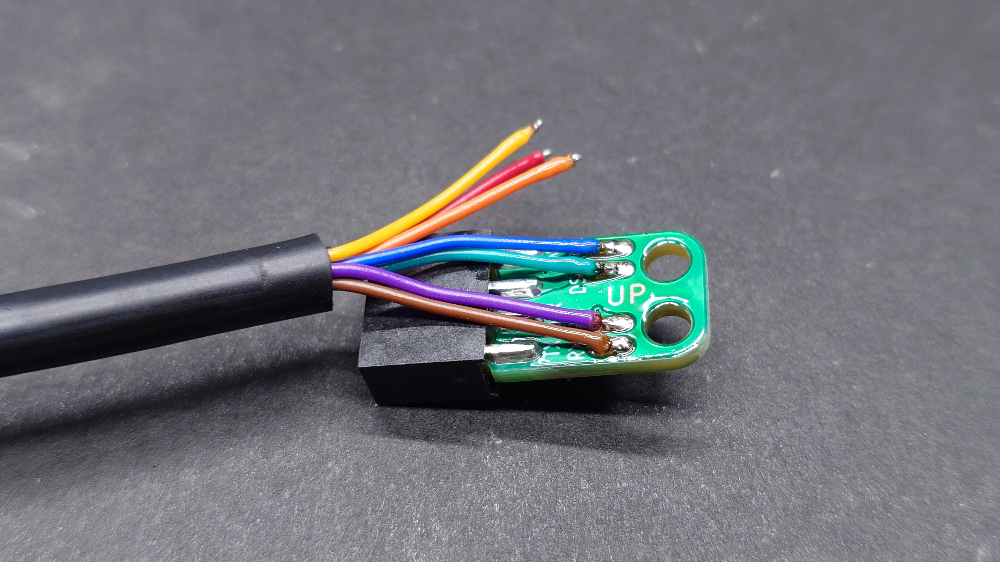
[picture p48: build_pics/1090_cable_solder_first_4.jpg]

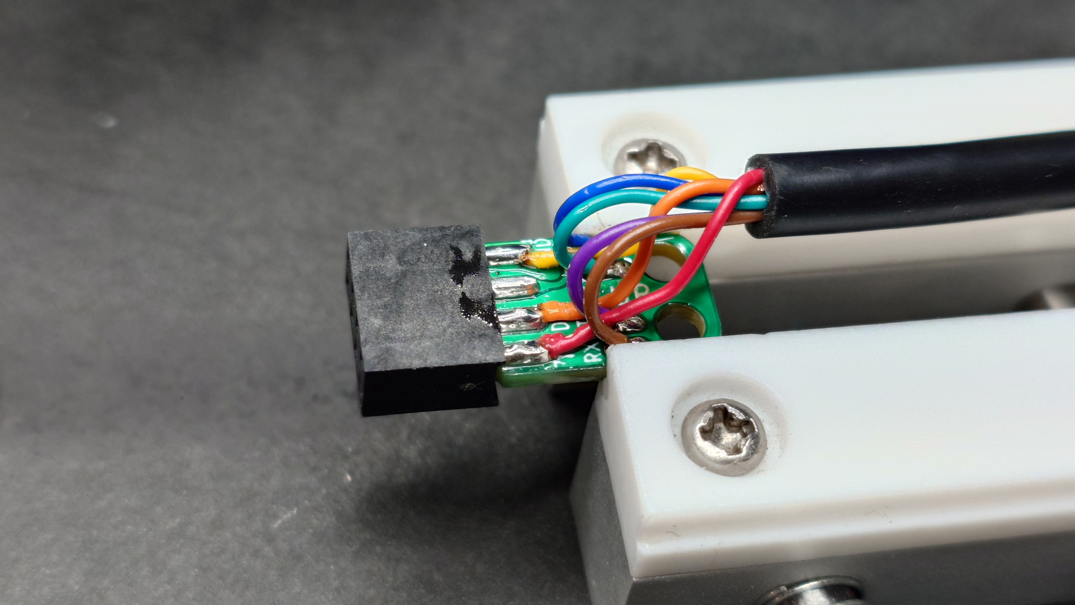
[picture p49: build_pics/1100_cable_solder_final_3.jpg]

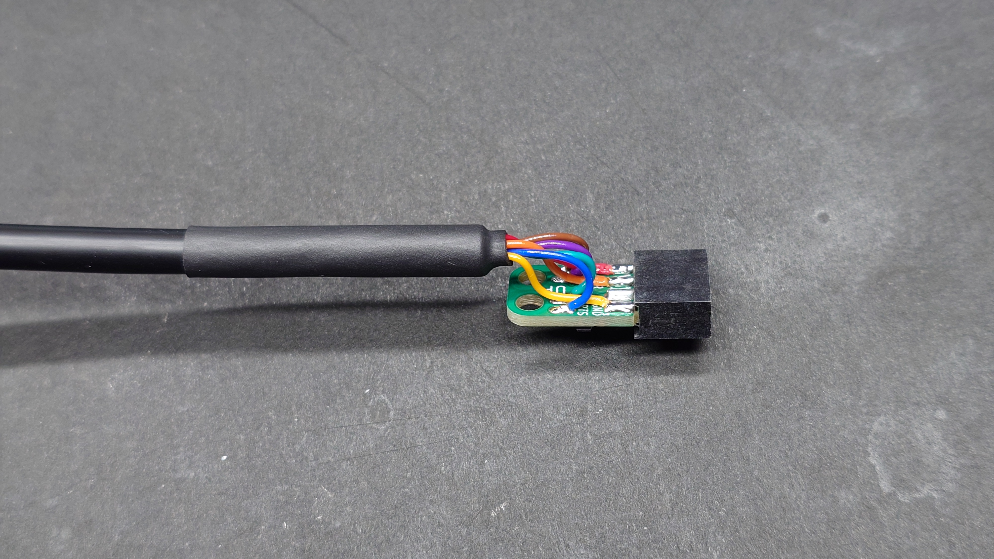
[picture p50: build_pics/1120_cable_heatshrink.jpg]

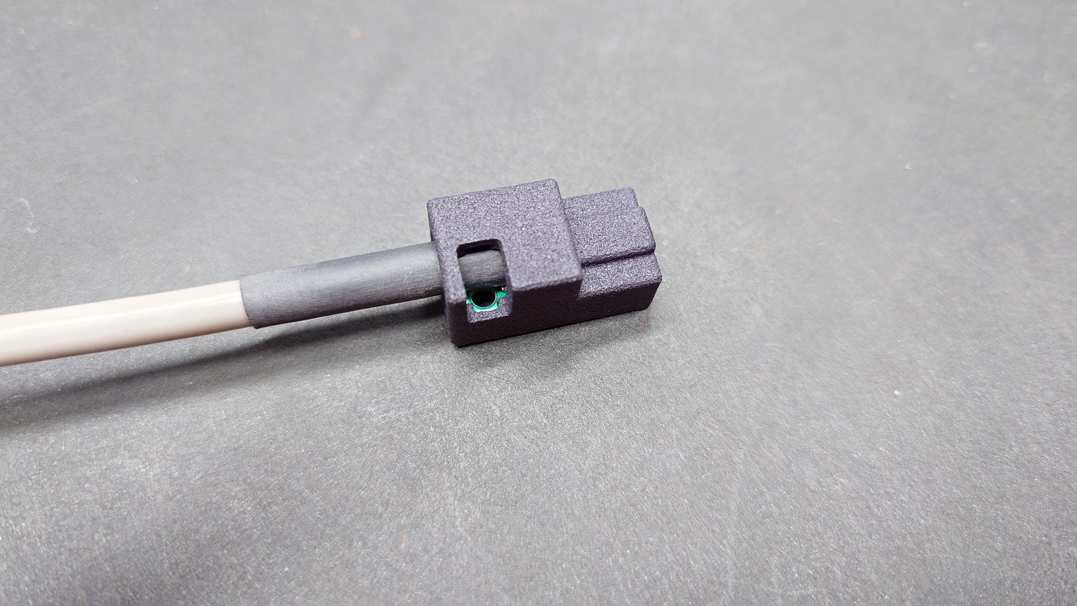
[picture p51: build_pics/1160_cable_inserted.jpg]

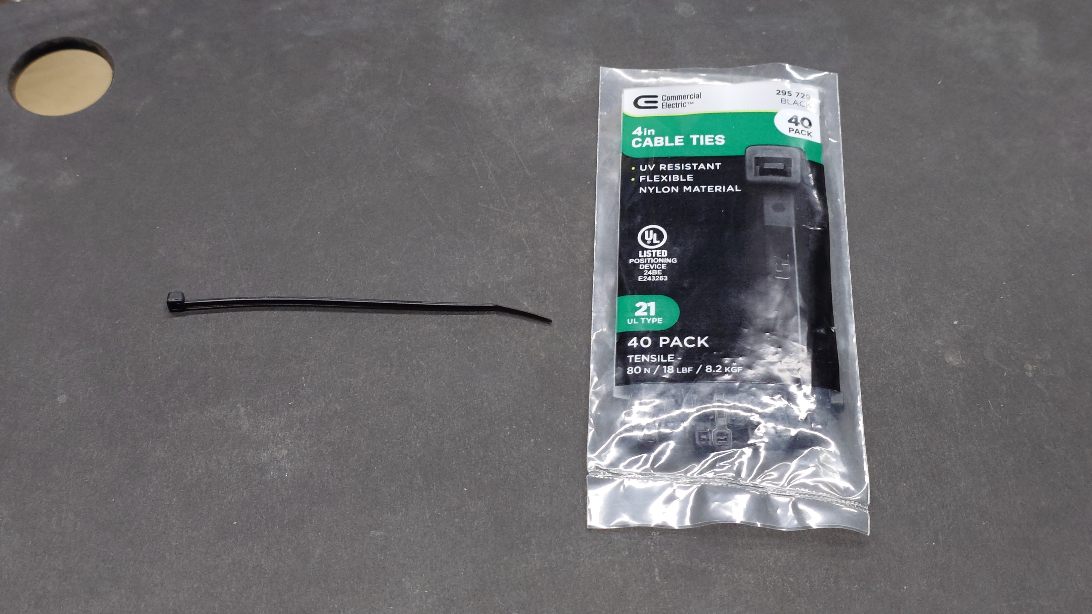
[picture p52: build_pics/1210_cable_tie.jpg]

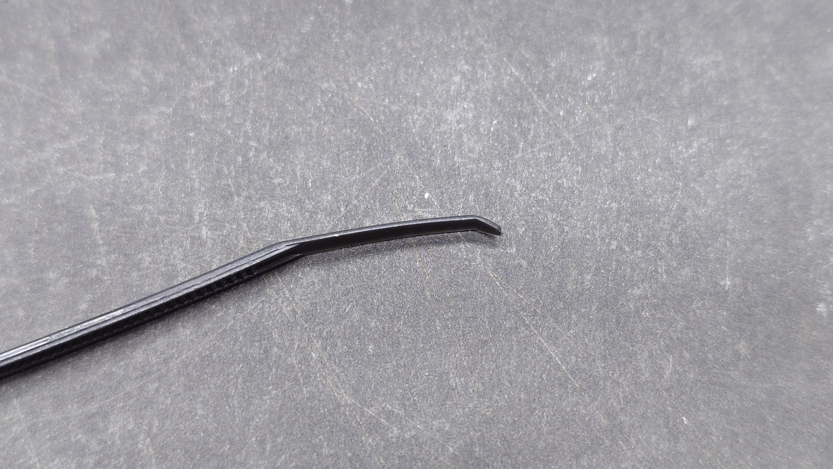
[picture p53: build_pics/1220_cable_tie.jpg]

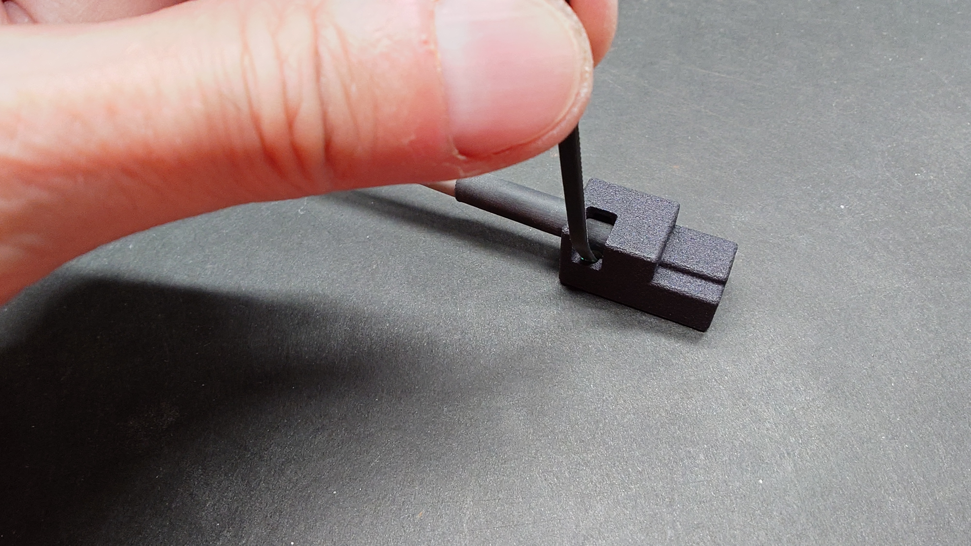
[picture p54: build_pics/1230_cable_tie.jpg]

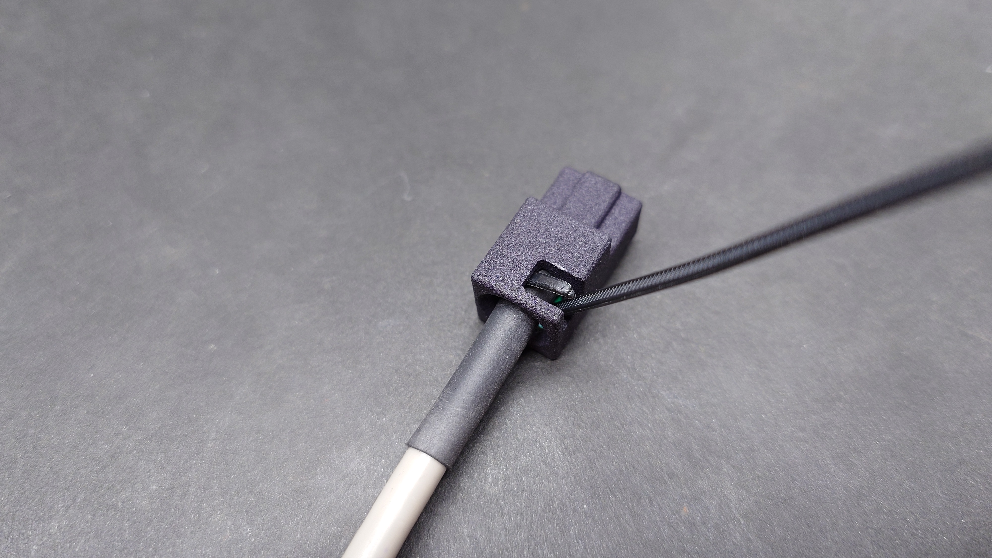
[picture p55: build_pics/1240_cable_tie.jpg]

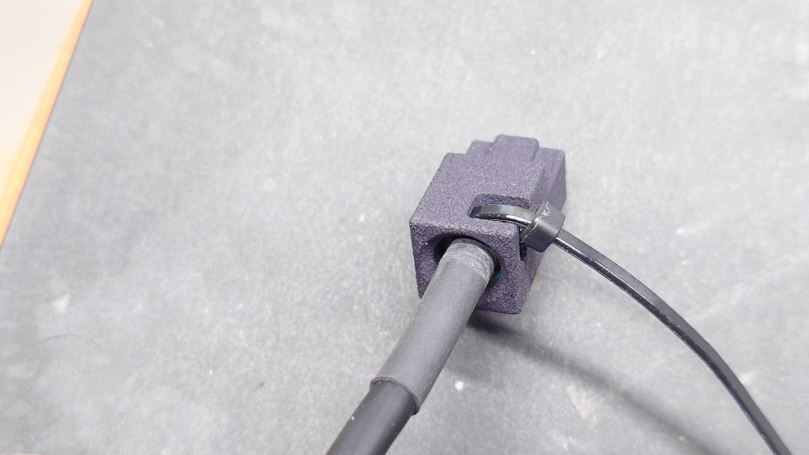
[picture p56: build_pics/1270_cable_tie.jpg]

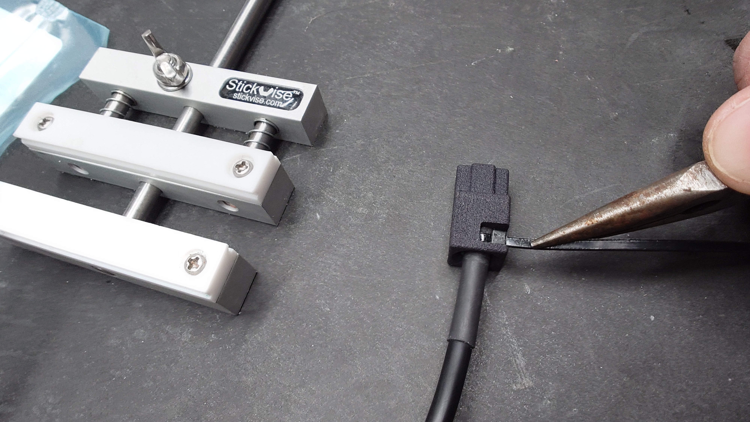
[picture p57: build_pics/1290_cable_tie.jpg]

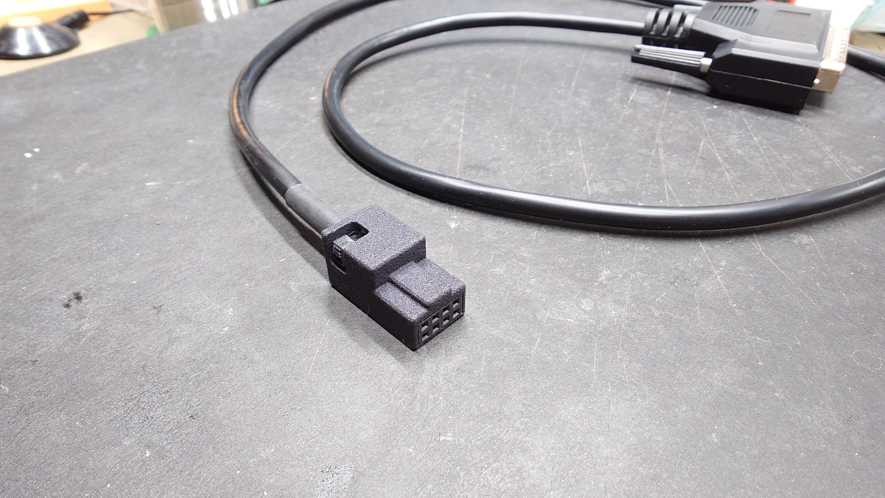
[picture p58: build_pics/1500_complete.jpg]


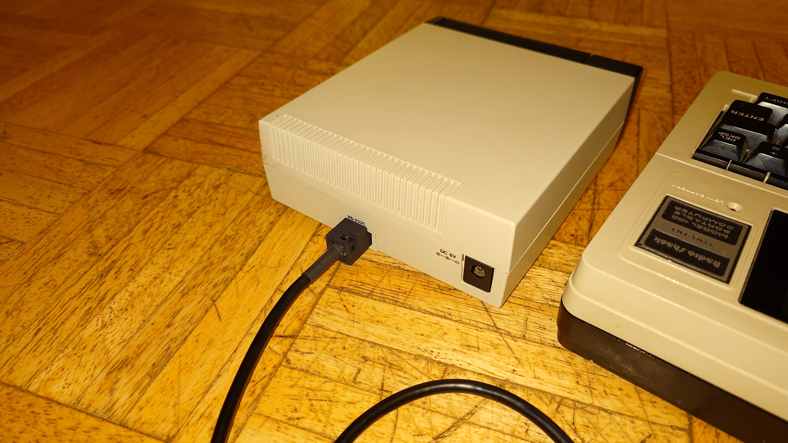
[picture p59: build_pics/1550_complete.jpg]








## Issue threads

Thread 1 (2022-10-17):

Freeze on formatting disk in TS-DOS

explit7, 2022-10-17:
Hello Brian and thank you very much for your great projects! I purchased all parts needed and soldered the cable.
When i connect my Brother FB100 Floppy drive to my NEC PC-8201 and try to read the Floppy with TS-DOS -
the disk is being accessed. Access LED light up, drive reads the floppy and TS-DOS tells me that the disk is not formatted.
It shows me the message:
`Insert Floppy and press "Y" to format`
If i press the Y-Key - the computer freezes and i need to reset it to be able to read again.

Is there any other way to test the floppy on the NEC PC-8201?

Thank you very much

bkw777, 2022-10-18:
There's a few things to check / know

If you didn't replace the belt in the drive, it definitely needs a new belt. The original belts are all turned to goo by now. So google up a FRW-8.5 belt and discard any that cost more than $10.

The freeze is not really a freeze, it would probably time out on it's own after about 2 minutes. I don't remember specifically if TS-DOS has such a time out, I just say that because at the protocol level, the format command doesn't return any kind of ongoing progress nor is there a way to poll for progress except at the end when it's all done, and that takes over 100 seconds on a normal working drive. The whole time the drive is busy formatting, there is nothing passing over the wire, and if the client even tried to send anything it would just cause an error since the drive firmware isn't expecting it.

So if the drive has a bad belt, the client can still communicate with the drive, and all disks would look like unformatted, and a format command would probably just cause the drive to spin for 100 seconds, or maybe less before the drive could even tell that it did't work. The format command does do it's own verify but I don't know if it does that for each track along the way or only at the end after doing all tracks. Even if it does try to veryify after the first track and detect the failure right away, TS-DOS might be waiting 100 seconds before even looking (unlikely but possible).

When you wired up the cable, did you verify with a continuity tester that you got the right DB25 pin numbers connected to the matching numbers on the pcb? I included the color codes for the cables I used but you really can't trust the colors.

Also you got the polarity right, the extra 2 femal header positions to make the polarity bump are on the opposite side from the transistors?

The symptoms are all consistent with needing a belt.

bkw777, 2022-10-18:
You can test iwth pdd.sh from linux or mac. You'll need a usb-serial adapter and a particular 9-25 adapter or a combination of adapters. I have links and info all in a hardware document on the pdd.sh readme.
github.com/bkw777/pdd.sh
It is exactly a swiss army knife for operating and debugging a drive. Unfortunately it doesn't have great docs. Start with the readme and then look at all the cases in the big case statement in do_cmd(), and follow each of those to whatever function it calls to figure out the parameters for things not in the readme.

But the easy thing is just if you issue a condition or status command, and geat a meaningful respoonse at all, then you have cleared the cable. Connect the drive, turn the drive on, then start pdd.sh in tpdd1 mode, and 9600 speed because fb-100 only runs at 9600, and issue a "cond" command.

```
bkw@fw:~$ BAUD=9600 DEBUG=2 pdd1
1) /dev/ttyUSB0
2) /dev/ttyUSB1
Which serial port is the TPDD drive on? 2
Using port "/dev/ttyUSB1"
speed 9600 baud; rows 0; columns 0; line = 0;
intr = ^C; quit = ^\; erase = ^?; kill = ^U; eof = ^D; eol = <undef>; eol2 = <undef>; swtch = <undef>; start = ^Q; stop = ^S; susp = ^Z; rprnt = ^R; werase = ^W;
lnext = ^V; discard = ^O; min = 1; time = 1;
-parenb -parodd -cmspar cs8 hupcl -cstopb cread clocal crtscts
-ignbrk -brkint -ignpar -parmrk -inpck -istrip -inlcr -igncr -icrnl -ixon -ixoff -iuclc -ixany -imaxbel -iutf8
-opost -olcuc -ocrnl onlcr -onocr -onlret -ofill -ofdel nl0 cr0 tab0 bs0 vt0 ff0
-isig -icanon iexten -echo echoe echok -echonl -noflsh -xcase -tostop -echoprt echoctl echoke -flusho -extproc
PDD(opr:6.2,F)> cond
_init()
fonzie_smack()
ocmd_send_req: fmt="08" len="00" dat="" chk="F7"
tpdd_read: l=8 30 30 45 30 30 30 30 30
fcmd_read_ret: 00E00000
fcmd_read_ret: err:0="OK" res:224 len:0
Disk Write-Protected
Disk Changed
Disk Not Inserted
PDD(fdc:6.2,F)>
```

The tpdd_read: there shows the data read from the drive, and the rest parsed it, and the last few lines shows that it was a meaningful response not garbage. this was on a Purple Computing (same as fb-100 or tpdd1)

I only got prompted for the serial port because I had more than one usb serial adapter plugged in at the time.

Normally you don't bother manually using pdd1 vs pdd2 commands, just say "pdd commands..." and it automatically determines which kind of drive it is on startup. But in this case I just said the more explicit command to remove variables.

It doesn't automatically determine baud rate though. The default is 19200 because both tpdd1 and tpdd2 run at 19200, but fb-100 is hardwired to 9600. There is a little door on the bottom and it will run at 19200 if you flip all the dip switches to off. But on fb-100 I think usually there is no dip switch installed and there is just a solder blob bridging one of the positions. You could clear that solder blob and the drive will run at 19200 if you wanted. My purple computing has switches installed but I don't know if that was original or just the purple computing did that to theirs or some owner did it along the way. Then again... I don't think it makes actual operation much faster. Most of the time is spent waiting for the drive hardware to actually read/write the disk, and each side always waiting for the other side to process and ack each 128 byte command/packet before proceeding to the next.

bkw777, 2022-10-18:
Better yet
Or DEBUG=3
This time with only one usb adapter plugged in, and letting it automatically figure out the drive model,
and using the status command instead of the condition command. They both report drive status, but "cond" is an FDC-mode command and ends up switching the drive from opr to fdc mode which just adds another complicating detail so let's use status instead.

If you try this and get a drive status like at the bottom of this, then you have verified the cable and serial connnection and communication both directions. If not, then paste whatever you get here and maybe I can say where it went wrong.
This is a rebadged FB-100 with no disk inserted. Your drive even with a bad belt should produce identical output to this.

```
bkw@fw:~$ BAUD=9600 DEBUG=3 pdd
get_tpdd_port()
Using port "/dev/ttyUSB0"
open_com()
set_stty()
speed 9600 baud; rows 0; columns 0; line = 0;
intr = ^C; quit = ^\; erase = ^?; kill = ^U; eof = ^D; eol = <undef>; eol2 = <undef>; swtch = <undef>; start = ^Q; stop = ^S; susp = ^Z; rprnt = ^R; werase = ^W;
lnext = ^V; discard = ^O; min = 1; time = 1;
-parenb -parodd -cmspar cs8 hupcl -cstopb cread clocal crtscts
-ignbrk -brkint -ignpar -parmrk -inpck -istrip -inlcr -igncr -icrnl -ixon -ixoff -iuclc -ixany -imaxbel -iutf8
-opost -olcuc -ocrnl onlcr -onocr -onlret -ofill -ofdel nl0 cr0 tab0 bs0 vt0 ff0
-isig -icanon iexten -echo echoe echok -echonl -noflsh -xcase -tostop -echoprt echoctl echoke -flusho -extproc
PDD(opr:6.2,F)> status
do_cmd(status)
_init()
fonzie_smack()
tpdd_drain()
tpdd_check()
tpdd_write(4D 31 0D)
tpdd_drain()
tpdd_check()
tpdd_write(5A 5A 08 00 F7)
tpdd_drain()
tpdd_check()
tpdd_write(4D 31 0D)
tpdd_drain()
tpdd_check()
ocmd_pdd2_unk23()
ocmd_send_req(23)
calc_cksum(23 00):DC
ocmd_send_req: fmt="23" len="00" dat="" chk="DC"
tpdd_write(5A 5A 23 00 DC)
ocmd_read_ret()
ocmd_read_ret: reading 2 bytes (fmt len)
tpdd_read(2)
tpdd_wait()
tpdd_check()
tpdd_check()
Detected TPDD1
ocmd_ready()
ocmd_send_req(07)
calc_cksum(07 00):F8
ocmd_send_req: fmt="07" len="00" dat="" chk="F8"
tpdd_write(5A 5A 07 00 F8)
ocmd_read_ret(5000)
ocmd_read_ret: reading 2 bytes (fmt len)
tpdd_read(2 5000)
tpdd_wait(5000)
tpdd_check()
tpdd_check()
tpdd_read: l=2 tpdd_wait()
tpdd_check()
tpdd_wait()
tpdd_check()
12 01
ocmd_read_ret: reading 1 bytes (data)
tpdd_read(1)
tpdd_wait()
tpdd_check()
tpdd_read: l=1 tpdd_wait()
tpdd_check()
71
ocmd_read_ret: reading 1 byte (checksum)
tpdd_read(1)
tpdd_wait()
tpdd_check()
tpdd_read: l=1 tpdd_wait()
tpdd_check()
7B
ocmd_read_ret: fmt=12 len=01 dat=(71) chk=7B
verify_checksum(12 01 71 7B)
calc_cksum(12 01 71):7B
verify_checksum: given:7B calc:7B
ocmd_check_err()
ocmd_check_err: ret_fmt=12 ret_len=01 ret_dat=(71) read_err="0"
ocmd_check_err: 71:Disk Not Inserted or Disk Change Error
Not Ready

status: Disk Not Inserted or Disk Change Error
PDD(opr:6.2,F)>
```

bkw777, 2022-10-18:
https://github.com/bkw777/pdd.sh/blob/main/hardware.md

bkw777, 2022-10-18:
Actually... I'm dumb, if you got a message from TS-DOS saying disk not formatted, I think that already proves the communication is good, so you can skip pdd.sh and just open the case to check the belt and I bet it'll be bad.

explit7, 2022-10-18:
Hello Brian!

   Thank you for taking so much time for my problem and your very good explanations.

   i will go for a new belt and will let you know!

   thank you very much!

   Pawel

   On October 18, 2022 at 6:09 AM Brian K. White ***@***.***> wrote:

    Actually... I'm dumb, if you got a message from TS-DOS saying disk not formatted, I think that already proves the communication is good, so you can skip pdd.sh and just open the case to check the belt and I bet it'll be bad.
    —Reply to this email directly, view it on GitHub, or unsubscribe.You are receiving this because you authored the thread.Message ID: ***@***.***>

bkw777, 2023-12-13:
What ever happened?

explit7, 2023-12-26:
I got a new belt and anything was fine! Thanks again!

Closed 2023-12-25.

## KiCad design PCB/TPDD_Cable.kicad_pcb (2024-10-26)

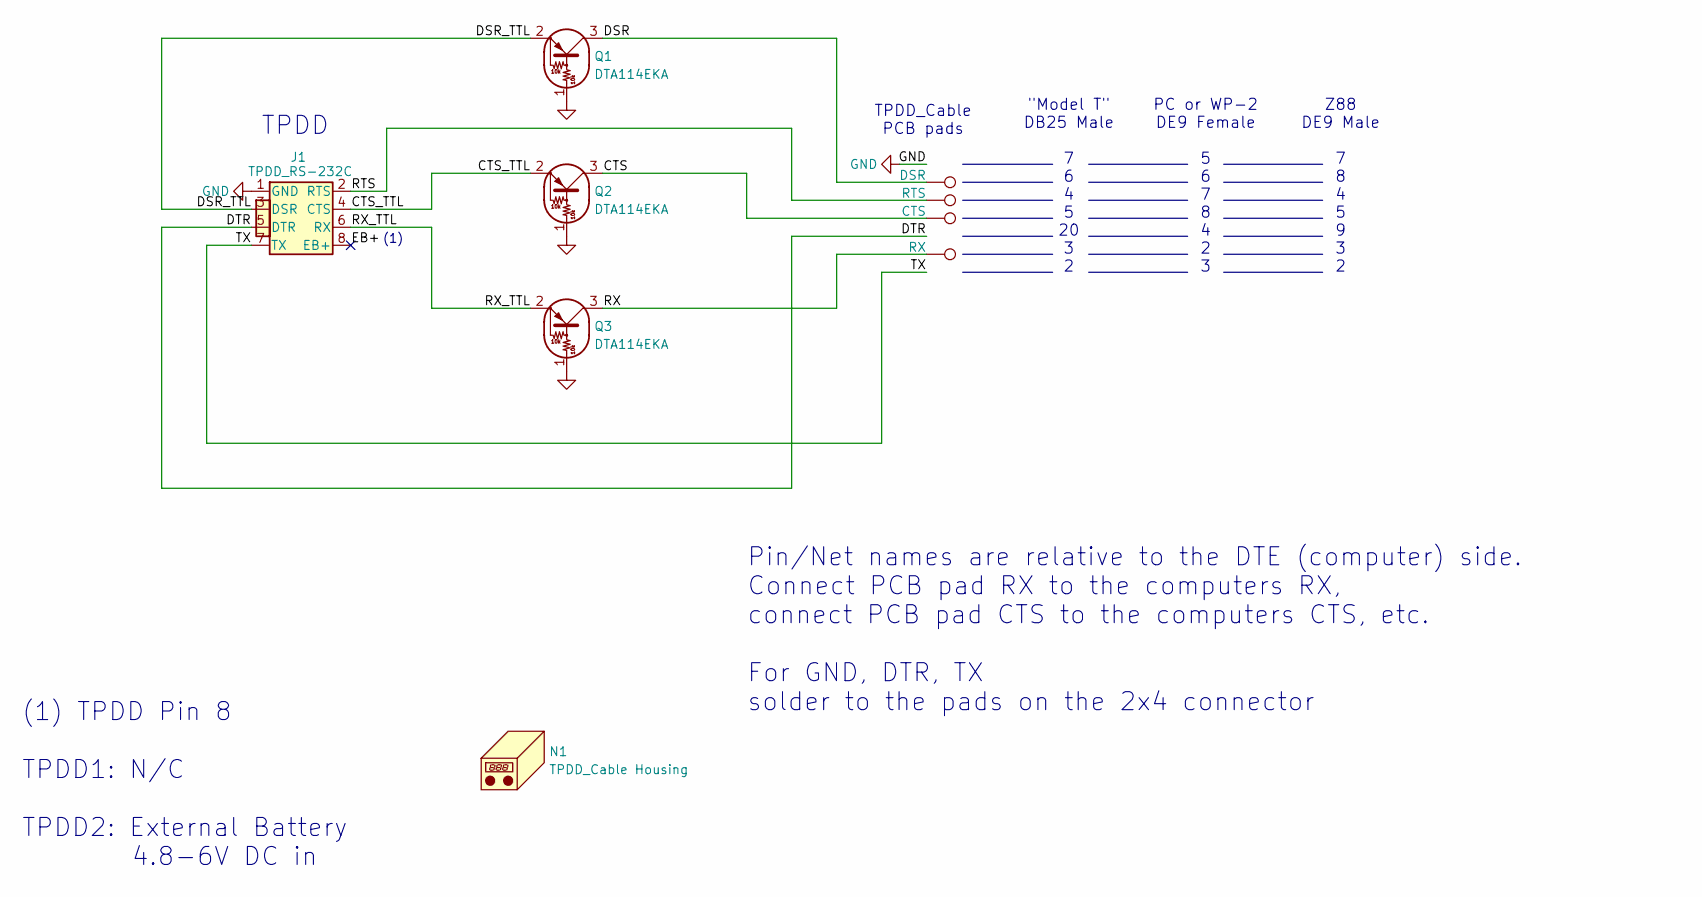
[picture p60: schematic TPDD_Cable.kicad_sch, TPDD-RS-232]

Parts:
J1: TPDD_RS-232C; 2x4x2.54mm_edge_mount; MPN M20-7830442
N1: TPDD_Cable Housing; TPDD_Cable_Housing
P3: RX; SMD_1.2x3
P4: RTS; SMD_1.2x3
P5: CTS; SMD_1.2x3
P6: DSR; SMD_1.2x3
Q1, Q2, Q3: DTA114EKA; SC-59; MPN DTA114EKA

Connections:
/CTS: P5.1, Q2.3 (C)
/CTS_TTL: J1.4 (CTS), Q2.2 (E)
/DSR: P6.1, Q1.3 (C)
/DSR_TTL: J1.3 (DSR), Q1.2 (E)
/DTR: J1.5 (DTR)
/EB+: J1.8 (EB+)
/RTS: J1.2 (RTS), P4.1
/RX: P3.1, Q3.3 (C)
/RX_TTL: J1.6 (RX), Q3.2 (E)
/TX: J1.7 (TX)
GND: J1.1 (GND), Q1.1 (B), Q2.1 (B), Q3.1 (B)

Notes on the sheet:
Z88 DE9 Male 7 8 4 5 9 3 2
TPDD_Cable PCB pads
(1) TPDD Pin 8 TPDD1: N/C TPDD2: External Battery 4.8-6V DC in
(1)
Pin/Net names are relative to the DTE (computer) side. Connect PCB pad RX to the computers RX, connect PCB pad CTS to the computers CTS, etc. For GND, DTR, TX solder to the pads on the 2x4 connector
PC or WP-2 DE9 Female 5 6 7 8 4 2 3
TPDD
"Model T" DB25 Male 7 6 4 5 20 3 2

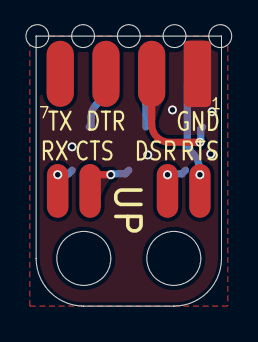
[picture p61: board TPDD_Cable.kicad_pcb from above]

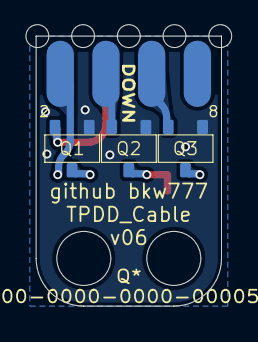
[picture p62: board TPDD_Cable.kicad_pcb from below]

Board: 2 copper layers, 10.3 x 15.0 mm, 9 parts (3 on the bottom side), 8 nets.

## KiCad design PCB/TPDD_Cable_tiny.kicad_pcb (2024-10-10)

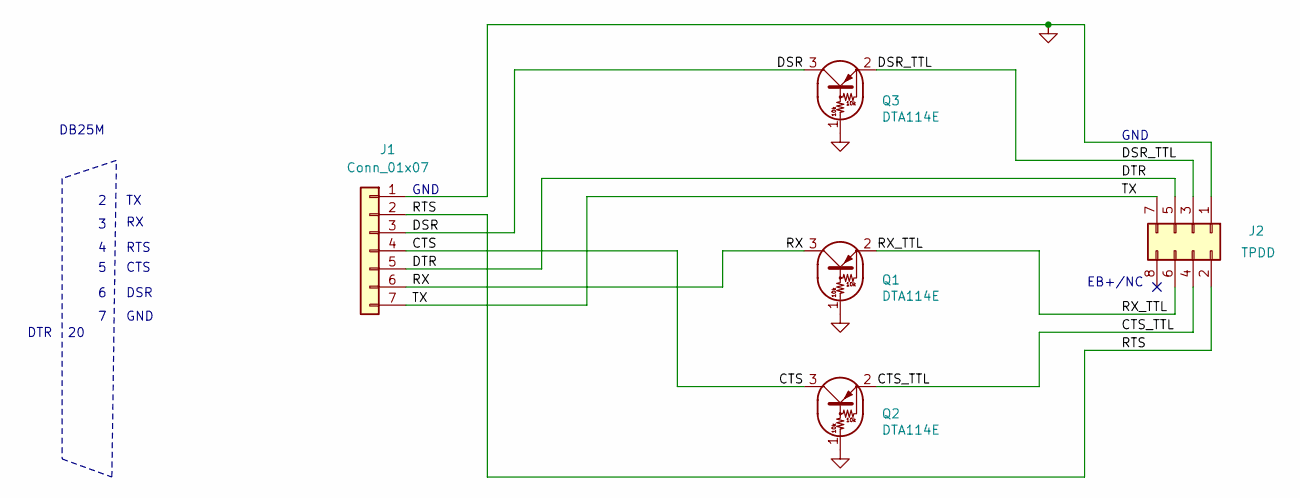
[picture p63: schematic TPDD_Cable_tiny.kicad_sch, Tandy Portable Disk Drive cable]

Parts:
J1: Conn_01x07; 1x7x2mm
J2: TPDD; 2x4_header_on_edge
Q1, Q2, Q3: DTA114E; SC-59

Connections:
/CTS_232: J1.4, Q2.3 (C)
/CTS_TTL: J2.4, Q2.2 (E)
/DSR_232: J1.3, Q3.3 (C)
/DSR_TTL: J2.3, Q3.2 (E)
/DTR: J1.5, J2.5
/RTS: J1.2, J2.2
/RX_232: J1.6, Q1.3 (C)
/RX_TTL: J2.6, Q1.2 (E)
/TX: J1.7, J2.7
GNDS: J1.1, J2.1, Q1.1 (B), Q2.1 (B), Q3.1 (B)

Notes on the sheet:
GND
DB25M
RTS
CTS
DTR
EB+/NC
DSR

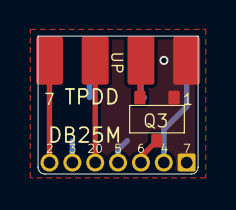
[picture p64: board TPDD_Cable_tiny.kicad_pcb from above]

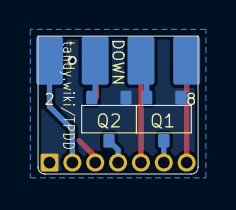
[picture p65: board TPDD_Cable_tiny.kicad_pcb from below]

Board: 2 copper layers, 8.9 x 7.7 mm, 5 parts (2 on the bottom side), 10 nets.

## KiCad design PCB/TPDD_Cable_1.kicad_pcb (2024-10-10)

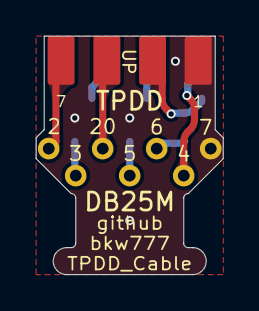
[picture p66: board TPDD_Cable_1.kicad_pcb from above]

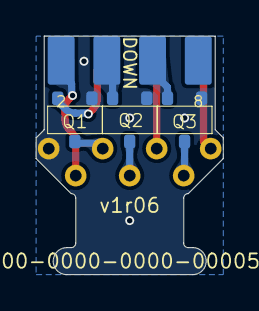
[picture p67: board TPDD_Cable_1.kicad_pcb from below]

Board: 2 copper layers, 10.4 x 13.2 mm, 11 parts (3 on the bottom side), 10 nets.

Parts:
J2: TPDD; 2-6-2_tpdd
P2: RX; PTH_0.65x1.2
P3: TX; PTH_0.65x1.2
P4: CTS; PTH_0.65x1.2
P5: RTS; PTH_0.65x1.2
P6: DTR; PTH_0.65x1.2
P7: GND; PTH_0.65x1.2
P20: DSR; PTH_0.65x1.2
Q1, Q2, Q3: DTA114EKA; SC-59

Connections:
/TPDD_Cable/CTS: P5.1, Q2.3 (C)
/TPDD_Cable/CTS_TTL: J2.4, Q2.2 (E)
/TPDD_Cable/DSR: P6.1, Q1.3 (C)
/TPDD_Cable/DSR_TTL: J2.3, Q1.2 (E)
/TPDD_Cable/DTR: J2.5, P20.1
/TPDD_Cable/RTS: J2.2, P4.1
/TPDD_Cable/RX: P3.1, Q3.3 (C)
/TPDD_Cable/RX_TTL: J2.6, Q3.2 (E)
/TPDD_Cable/TX: J2.7, P2.1
GND: J2.1, P7.1, Q1.1 (B), Q2.1 (B), Q3.1 (B)

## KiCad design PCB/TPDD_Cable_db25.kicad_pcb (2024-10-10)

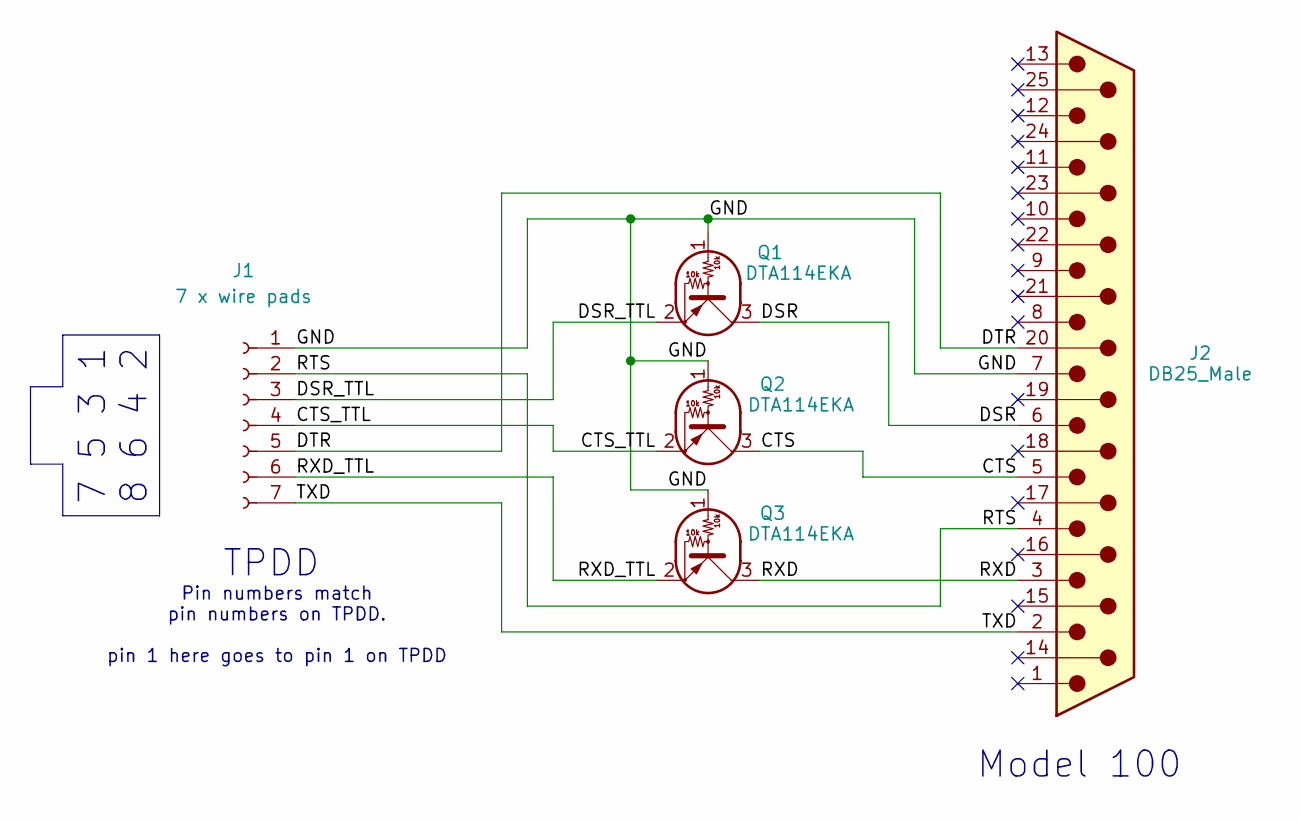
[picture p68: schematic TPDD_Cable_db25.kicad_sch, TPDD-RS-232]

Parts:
J1: 7 x wire pads; pins_1x7_2mm
J2: DB25_Male; DSUB-25_Male_EdgeMount_P2.77mm
Q1, Q2, Q3: DTA114EKA; SC-59

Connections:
/CTS: J2.5, Q2.3 (C)
/CTS_TTL: J1.4, Q2.2 (E)
/DSR: J2.6, Q1.3 (C)
/DSR_TTL: J1.3, Q1.2 (E)
/DTR: J1.5, J2.20
/GND: J1.1, J2.7, Q1.1 (B), Q2.1 (B), Q3.1 (B)
/RTS: J1.2, J2.4
/RXD: J2.3, Q3.3 (C)
/RXD_TTL: J1.6, Q3.2 (E)
/TXD: J1.7, J2.2

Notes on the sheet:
7 5 3 1 8 6 4 2
Model 100
TPDD
Pin numbers match pin numbers on TPDD. pin 1 here goes to pin 1 on TPDD

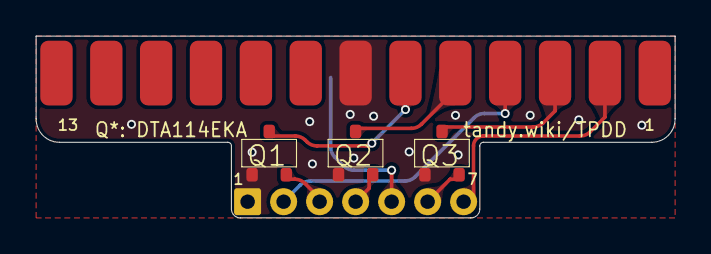
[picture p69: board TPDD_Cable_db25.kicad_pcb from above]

Board: 2 copper layers, 35.5 x 10.1 mm, 5 parts (0 on the bottom side), 10 nets.

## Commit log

2020-08-08 pack v1 board tighter
    [TPDD_Cable.kicad_pcb, TPDD_Cable_v1.kicad_pcb]
2020-09-07 add schematic svg for readme
2020-09-07 script to crop svg schematic plots
2020-09-07 add Z88 version
    [TPDD_Cable_Z88.kicad_pcb, TPDD_Cable_Z88.sch]
2020-09-23 add WP-2 version, add EB+ in schematics
    [TPDD_Cable.BOM.csv, TPDD_Cable_TINY.kicad_pcb, TPDD_Cable_WP2.kicad_pcb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]
2021-04-03 pcbway limits, readme
    [TPDD_Cable.kicad_pcb, TPDD_Cable_PITA.kicad_pcb, TPDD_Cable_TINY.kicad_pcb]
2021-04-26 bigger 2x4 solder pads, smaller wire holes
    [TPDD_Cable.kicad_pcb, TPDD_Cable_TINY.kicad_pcb, TPDD_Cable_WP2.kicad_pcb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]
2021-04-27 adjust board outline
    [TPDD_Cable.kicad_pcb, TPDD_Cable_WP2.kicad_pcb, TPDD_Cable_Z88.kicad_pcb]
2021-05-25 remove WP-2 and Z88 pcbs, put alternate wiring in readme instead
    [TPDD_Cable.kicad_pcb, TPDD_Cable_WP2.kicad_pcb, TPDD_Cable_WP2.sch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]
2021-05-25 pic of Z88 cable pinout
2021-05-25 pcb pad numbers pic
2021-05-25 pic of PC cable pinout
2021-05-25 db25m wiring pic
2022-10-02 kicad 6, ground zones
    [TPDD_Cable.kicad_pcb, TPDD_Cable.kicad_sch, TPDD_Cable.sch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]
2023-12-20 add cable tests to readme
    [TPDD_Cable.kicad_pcb, TPDD_Cable.kicad_sch]
2024-08-11 3d printed plug housing
    [TPDD_Cable.BOM.csv, TPDD_Cable.kicad_pcb, TPDD_Cable.kicad_sch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]
2024-08-14 pcb shape v012
    [2x4a.stl, 2x4b.stl, CableTie_M3_head.stl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]
2024-08-14 readme & bom
    [TPDD_Cable.BOM.csv]
2024-08-15 pcb version 3
    [TPDD_Cable.kicad_pcb, TPDD_Cable.kicad_sch, TPDD_Cable_Housing.scad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]
2024-08-15 housing & solder jig
    [TPDD_Cable_Housing.scad, TPDD_Cable_Housing_012.A.stl, TPDD_Cable_Housing_012.B.stl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]
2024-08-15 organize files
    [TPDD_Cable.kicad_pcb, TPDD_Cable.kicad_sch, TPDD_Cable_PITA.kicad_pcb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]
2024-08-16 plug housing
    [2x4a.stl, 2x4b.stl, CableTie_M3_head.stl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]
2024-08-17 housing 0.8mm min wall
    [TPDD_Cable.kicad_sch, TPDD_Cable_Housing.3A.stl, TPDD_Cable_Housing.3B.stl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]
2024-08-18 housing: 0.8mm min-wall & many small fixes. pcb: pull in v1 & v2 pcbs from master & fancy2
    [TPDD_Cable.kicad_sch, TPDD_Cable_1.kicad_pcb, TPDD_Cable_1.kicad_sch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]
2024-08-18 pcb names
    [TPDD_Cable_1.kicad_pcb, TPDD_Cable_2.kicad_pcb, TPDD_Cable_3.kicad_pcb]
2024-08-19 increase housing C max cable diam
    [TPDD_Cable_Housing.1C.stl, TPDD_Cable_Housing.2C.stl, TPDD_Cable_Housing.3C.stl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]
2024-08-20 housing readme
2024-10-10 pcb 2 is new default, smt wire pads
    [TPDD_Cable.kicad_pcb, TPDD_Cable.kicad_sch, TPDD_Cable_1.kicad_pcb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]
2024-10-12 transistors & wire pads placement
    [2x4a.stl, 2x4b.stl, CableTie_M3_head.stl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]
2024-10-23 correct DTE vs DCE signal names & DE9 pinout in schematic
    [TPDD_Cable.kicad_pcb, TPDD_Cable.kicad_sch, TPDD_Cable_Housing.scad]
2024-10-23 DTE vs DCE signal names & cable pinouts
2024-10-24 db25 pinout pics, enlarge ziptie holes to 3mm
    [TPDD_Cable.kicad_pcb, TPDD_Cable.kicad_sch]
2024-10-24 schematics notes text
    [TPDD_Cable.kicad_sch, TPDD_Cable_1.kicad_sch, TPDD_Cable_M4-tie.kicad_sch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]
2024-10-24 move via out of smt pad
    [TPDD_Cable.kicad_pcb]
2024-10-26 wire color charts
    [TPDD_Cable.kicad_pcb, TPDD_Cable.kicad_sch]
2024-10-30 fab bom & pics
    [TPDD_Cable.fab_bom.csv, TPDD_Cable.kicad_sch, TPDD_Cable_solder_jig.stl]
2024-10-31 bom & readme
    [TPDD_Cable.BOM.csv, TPDD_Cable.DigiKey_BOM.csv]
2024-11-04 schematic less clutter
    [TPDD_Cable.kicad_sch]
